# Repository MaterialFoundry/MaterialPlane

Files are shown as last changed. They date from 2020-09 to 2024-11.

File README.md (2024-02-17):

<b>This module requires external hardware that you probably don't have lying around, which means that you have to spend (at least) $40 on getting this module to work. The module is still in development, and probably contains bugs. Make sure that you're willing to risk spending money on something that might not work as intended.<br></b>
<br>
You can currently place a pre-order for pre-build hardware from my webshop: <a href="https://www.materialfoundry.nl/">https://www.materialfoundry.nl/</a><br>

### [Documentation](https://materialfoundry.github.io/MaterialPlane/)

# Material Plane
Material Plane is a <a href="https://foundryvtt.com/">Foundry VTT</a> module that allows physical minis to be tracked by Foundry when using a horizontally mounted TV. This allows you to bring the joy of physical minis into Foundry.<br>
<br>
There are currently 2 ways to track minis:<br>

## Material Plane sensor
The system consists of an IR sensor, and IR enabled mini bases. These bases contain IR LEDs that are tracked by the sensor. The sensor then relays this information to foundry over WiFi, where the information is interpreted as token movement.<br>
You can use any TV, monitor or projector for this.<br>
There is a pre-assembled and advanced version of the hardware for sale on the [Material Foundry webshop](https://www.materialfoundry.nl/), or it is possible to build DIY hardware.

## Touch Screen
There is currently experimental support for touch screen devices (broken in Foundry v11, though). Either capacitive touch screens or normal TVs with an IR touch frame can work.<br>
<br>
Please take a look at [this](https://materialfoundry.github.io/MaterialPlane/hardwareComparison/) page for a comparison between the Material Plane sensor and touch screen.<br>

## Trailer
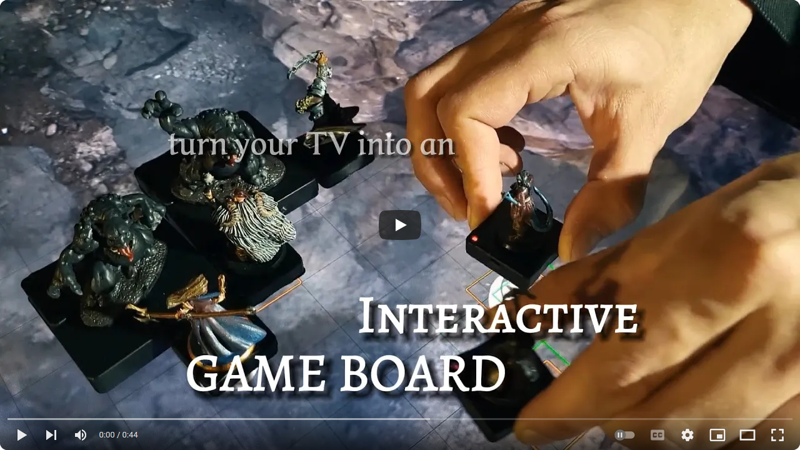
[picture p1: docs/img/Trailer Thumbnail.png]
Youtube Video (https://www.youtube.com/watch?v=VVTjNrCfUwM "Trailer")


# Important Links
* [Documentation](https://materialfoundry.github.io/MaterialPlane/)
* [Issues/Feature requests](https://github.com/MaterialFoundry/MaterialPlane/issues)
* [Main repository](https://github.com/materialfoundry/materialplane)
* [Foundry module](https://github.com/MaterialFoundry/MaterialPlane_Foundry) ([Releases](https://github.com/MaterialFoundry/MaterialPlane_Foundry/releases))
* [Sensor firmware](https://github.com/MaterialFoundry/MaterialPlane_Sensor) ([Releases](https://github.com/MaterialFoundry/MaterialPlane_Sensor/releases))
* [Base firmware](https://github.com/MaterialFoundry/MaterialPlane_Base) ([Releases](https://github.com/MaterialFoundry/MaterialPlane_Base/releases))
* [Pen firmware](https://github.com/MaterialFoundry/MaterialPlane_Pen) ([Releases](https://github.com/MaterialFoundry/MaterialPlane_Pen/releases))
* [Material Companion](https://github.com/MaterialFoundry/MaterialCompanion) ([Releases](https://github.com/MaterialFoundry/MaterialCompanion/releases))
* [Arduino core](https://github.com/MaterialFoundry/MaterialFoundry_Arduino) ([Releases](https://github.com/MaterialFoundry/MaterialFoundry_Arduino/releases))
* [3D models](https://github.com/MaterialFoundry/MaterialPlane_Models)
* [Discord server](https://discord.gg/3hd4G6TkmA)
* [Patreon](https://www.patreon.com/materialfoundry)

## Software Versions & Module Incompatibilities
<b>Foundry VTT:</b> v10 & v11<br>
<b>Module Incompatibilities:</b> When moving tokens, Foundry's click and drag system is bypassed. So modules that depend on that functionality might not work.<br>

## Feedback
If you have any suggestions or bugs to report, feel free to contact me on Discord (Cris#6864), or send me an email: cdeenen@outlook.com.

## Credits
<b>Author:</b> Cristian Deenen (Cris#6864 on Discord)<br>
<br>
Please consider supporting me on <a href="https://www.patreon.com/materialfoundry">Patreon</a>, and feel free to join the Material Foundry <a href="https://discord.gg/3hd4G6TkmA">Discord</a> server.

## Abandonment
Abandoned modules are a (potential) problem for Foundry, because users and/or other modules might rely on abandoned modules, which might break in future Foundry updates.<br>
I consider this module abandoned if all of the below cases apply:
<ul>
  <li>This module/github page has not received any updates in at least 3 months</li>
  <li>I have not posted anything on "the Foundry" and "the League of Extraordinary Foundry VTT Developers" Discord servers in at least 3 months</li>
  <li>I have not responded to emails or PMs on Discord in at least 1 month</li>
  <li>I have not announced a temporary break from development, unless the announced end date of this break has been passed by at least 3 months</li>
</ul>
If the above cases apply (as judged by the "League of Extraordinary Foundry VTT Developers" admins), I give permission to the "League of Extraordinary Foundry VTT Developers" admins to assign one or more developers to take over this module, including requesting the Foundry team to reassign the module to the new developer(s).<br>
I require the "League of Extraordinary Foundry VTT Developers" admins to send me an email 2 weeks before the reassignment takes place, to give me one last chance to prevent the reassignment.<br>
I require to be credited for my work in all future releases.

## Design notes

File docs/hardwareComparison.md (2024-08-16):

# Hardware Comparison
There are a few options when it comes down to the tracking of physical miniatures. This page will give an overview of these options, and a comparison between them.

## Options

### Material Plane Hardware

The first option would be to use a Material Plane sensor. The setup consists of 2 parts:

1. A sensor, which is mounted above the TV, and basically functions like an IR camera
2. Mini bases, which are placed underneath the mini and contain an IR LED which can be tracked by the sensor

There are 2 variants, the DIY variant and the production variant. The DIY variant has to be assembled by the user, while the production variant comes pre-assembled, and is available at the [Material Foundry webshop](https://www.materialfoundry.nl/).<br>
The main differences between the two variants can be found in the comparison below.<br>

The Material Plane sensor can be used on almost any display, for example a normal TV, or a projector.<br>

Because the minis are only detected when they are moved, there is no limit the the amount of minis you can have on the table. There is, however, a limit to the amount of minis that can be moved at the same time: 4 for the DIY sensor and 16 for the production sensor.<br>

Other forms of interaction (besides moving minis) is not possible for the DIY sensor, while the production sensor supports a special pen that can be used like a mouse to open doors, draw shapes, place templates, etc.<br>

Because the sensor is mounted above the TV, contact with the TV while moving minis is not required, unlike other setups. This means that minis can be raised up into the air in order for them to be moved over other minis.

### Infrared Touch Screen
<b>Material Plane support for touch screens is currently experimental. It is not yet clear how well it actually works, so it is currently not advisable to purchase one specifically for this purpose.</b><br>

An IR touch screen uses IR LEDs on 2 sides of the screen, and sensors on the other 2 sides. By placing a finger (or mini) on top of the screen, a shadow is cast on the sensors, because the IR light cannot pass through your finger. This is then converted to a position, which is interpreted as a touch by the computer.<br>

These touch screens can generally detect up to 10 touch points, however, these are not completely independent. Because the touch points cast a shadow, blind spots (where no touch is detected) are possible, and touches on one side of the display can influence the detected position of other touch points.<br>

Because the IR LEDs and sensors are slightly above the TV, it might be necessary to place the minis on a small platform to ensure that they are detected by the sensors.<br>

A non-touch display can quite easily be converted to an IR touch display through an IR touch frame. They can be easily found on, for example, Amazon for around $150 to $300 (depending on size and vendor).<br>

Other forms of interaction (besides moving minis) is possible, but is limited by the algoritm that distinguishes minis from other touches.

### Capacitive Touch Screen
<b>Material Plane support for touch screens is currently experimental. It is not yet clear how well it actually works, so it is currently not advisable to purchase one specifically for this purpose.</b><br>

A capacitive touch screen uses capacitive sensing to detect touches. I will not go into detail on how this works, for more information, take a look on [Wikipedia](https://en.wikipedia.org/wiki/Capacitive_sensing). The most important things are that capacitive touch screens only detect certain objects, such as fingers, while other objects are not detectable. This requires some modification to each mini that has to be detected, to basically create electrical contact between the screen and a hand through the mini. This could be done by, for example, applying copper tape to the bottom of the mini, with a piece of that tape extending up, so that it can be touched when the mini is moved.<br>

Unlike an Infrared touch frame, the touch points of a capacitive touch screen are independent. The number of detectable touch points is generally 10, but this can be higher or lower, depending on the display. Depending on how the minis are detected, this limit might not be important. In the above case (using copper tape), the mini is only detected when the mini is touched, therefore you could add as many minis as you like, as long as you only touch up to 10 at the same time.<br>

Big displays with built-in capacitive touch screens are hard to find and expensive. Capacitive touch can be added to existing non-touch displays (search for 'touch foil' or 'pcap touch foil'), but these are more difficult to find than IR touch frames. These foils generally have to be glued to the display or a separate glass pane, which can be difficult to do properly (due to trapped bubbles)<br>

Other forms of interaction (besides moving minis) is possible, but is limited by the algoritm that distinguishes minis from other touches.<br>

## Comparison
| |DIY|Production|IR Touch|Capacitive Touch|
|-|-|-|-|-|
|Max nr of minis on TV|Unlimited|Unlimited|10<sup>1</sup>|Unlimited<sup>2</sup>|
|Max nr of simultaneously moved minis<sup>3</sup>|4|16|10<sup>1</sup>|10|
|Other interaction methods<sup>4</sup>|No|Yes (through pen)|Yes (potentially limited)|Yes (potentially limited)|
|Required hardware|Sensor + Bases|Sensor + Bases|Screen and Touch Frame<sup>5</sup>|Just the screen<sup>6</sup>|
|Detection limitations|Line of sight required<sup>7</sup>|Line of sight required<sup>7</sup>|Touch points are not independent, contact with TV must be maintained|Contact with TV must be maintained|
|Display limitations|Can work on any display, but with size limitation<sup>8</sup>|Can work on any display, but with size limitation<sup>8</sup>|Requires either built-in touch, or a fitting touch frame|Requires either built-in touch, or a fitting touch foil|
|Mini movement method|Button press on base|Touch sensors on left and right side of the base|Raise a mini and then place it down again before moving the mini|Touching the conductive part of the mini<sup>2</sup>|
|Mini identification<sup>9</sup>|Location based|ID based|Location based|Location based|
|Portability|Can be easily transported somewhere else, to be used on a different display|Can be easily transported somewhere else, to be used on a different display|Requires the display (or touch frame) to be transported|Requires the display to be transported|
|Availablility|Must be built by yourself, some parts can be difficult to source|[Webshop](https://www.materialfoundry.nl/)|Touch frames are easy to find online|TVs with built-in capacitive touch are expensive and difficult to find, touch foil is difficult to find (price unknown)|
|Price (excluding display)|$50 - $100|$200-$400|$150 - $300|Intrated: very expensive, foil: $150-$400 |
|Current state|Functional|Functional|Experimental (broken in Foundry v11)|Experimental (broken in Foundry v11)|

<sup>1</sup> This is a theoretical limit, issues might occur before them due to the shadow effect, as described above<br>
<sup>2</sup> Depends on how the minis are detected, see above<br>
<sup>3</sup> This is a theoretical limit, your computer might not be able to process more than a few minis at the same time<br>
<sup>4</sup> This includes things like opening doors, placing templates, using measurement tools, etc<br>
<sup>5</sup> It might be necessary to place something underneath the mini to raise them, see above<br>
<sup>6</sup> Minis might require modification to add a conductive part, see above<br>
<sup>7</sup> Line of sight is required between the IR LED in the base and the sensor, care must be taken in how to hold a mini, and how to position minis on the base<br>
<sup>8</sup> The MP sensor is basically an IR camera, this means that any kind of display (TV, projector, etc) is compatible, as long as it's not too big. The maximum size depends on the distance between the sensor and the display, more info [here](https://github.com/CDeenen/MaterialPlane/wiki/Requirements#horizontally-mounted-tv).<br>
<sup>9</sup> Identification in this case means the method that is used to identify which mini is moved, and how this is related to the digital tokens. Location based means that it will link the token that's nearest to the mini, while ID based means that it is always known which mini is moved though a unique ID, regardless of the mini's location relative to its digital token.

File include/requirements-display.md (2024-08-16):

You'll need a TV, or some other display (monitor/projector) onto which the virtual tabletop is displayed.

{% if variant != 'touch' %}
For the Material Plane hardware (both DIY and production) you do have to consider the size of your TV, due to the limited detection angle of the sensor, see [Display-Sensor Distance section](requirements.md#display-sensor-distance) below.
Virtually any display will work, however, some older models (especially plasma and LCD displays with CCFL backlight) can emit infrared noise which might interfere with the sensor. To remedy this, you could add infrared-blocking foil to the display. Modern displays should not cause any issues.
{% endif %}

{% if variant == 'touch' %}
If the display has touch capabilities built-in there are no further requirements. Otherwise, make sure that your infrared touch frame or capacitive touch foil is the correct size and mounted correctly.
{% endif %}

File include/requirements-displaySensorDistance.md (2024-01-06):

In order for the sensor to detect minis across the whole display, the sensor needs to be located at a minimum distance above the display. The minimum distance depends on the size of the display, where a bigger display requires a larger distance.

{% if variant == 'production' %}
A [wide-angle lens]({{lensLink}}) can be installed in the production sensor when your display is too big and/or the distance to the ceiling is too small. The lens can either come pre-installed by selecting the option in the sensor product page, or it can be bought separately.
{% endif %}

The table below gives the minimum distance between the display and sensor. Measure the distance between the top of the display and the desired sensor mounting location (ceiling, microphone stand, etc). 

{% if variant == 'production' %}
Look at the row with your display size:

* If the measured distance is smaller than the value in the 'With Lens' column, your setup is incompatible with Material Plane. 
* If the distance is larger than the value in the 'With Lens' column but larger than the 'Without Lens' column, your setup requires the wide-angle lens. 
* If the distance is larger than the value in the 'Without Lens' column, the lens is not required, but can still be used to decrease the distance between sensor and display.
{% else %}
Look at the row with your display size, and if the value in the 'Distance' column is smaller than the measured distance, your setup is incompatible with Material Plane.
{% endif %}

Placing the sensor too far away from the display will result in reduced accuracy and potentially more jittery movement. For optimal results you should place the sensor as close to the minimum distance as possible (with some wiggle room for alignment). If you do not need the wide-angle lens, it's better to not have it installed.

Please note that these are just approximate values, assuming a 16:9 aspect ratio display and perfect sensor positioning while ignoring any manufacturing tolerances. Try to err on the safe side by subtracting a few cm/inches from the measured distance between display and sensor.

{% if variant == 'production' %}
Display Size | Production (No Lens) | Production (Lens) 
-------------|----------------------|-------------------
32" 	     | 109cm/43" 	        | 88cm/35"          
40" 	     | 134cm/53" 	        | 108cm/43"         
43" 	     | 144cm/57" 	        | 116cm/46"         
50" 	     | 166cm/66" 	        | 134cm/53"         
55" 	     | 182cm/72" 	        | 146cm/57"         
60" 	     | 198cm/78" 	        | 159cm/63"         
65" 	     | 214cm/85" 	        | 172cm/68"         
70" 	     | 230cm/91" 	        | 185cm/73"         
75" 	     | 246cm/97" 	        | 198cm/78"         
80" 	     | 278cm/110" 	        | 223cm/88"         
{% else %}
Display Size | Distance
-------------|--------
32" 	     | 120cm/47"
40" 	     | 150cm/59"
43" 	     | 160cm/63"
50" 	     | 187cm/74"
55" 	     | 205cm/81"
60" 	     | 224cm/88"
65" 	     | 243cm/96"
70" 	     | 261cm/103"
75" 	     | 280cm/110"
80" 	     | 289cm/114"
{% endif %}

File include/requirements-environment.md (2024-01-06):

Because of the way the sensor works, any infrared light around the TV can be interpreted as a base. For this reason, ambient infrared radiation and reflection should be avoided.

* Sunlight
* Infrared Emitting Lights
* VR Headsets
* Wii Sensor Bar
* Remote Controls

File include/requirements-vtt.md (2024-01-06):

Material Plane runs on a virtual tabletop. Currently only [Foundry VTT](https://foundryvtt.com/) is supported.

To use Foundry VTT, you need to purchase a license, and you need some way to host the Foundry server. For information on how to setup a Foundry VTT server, please refer to the [Foundry VTT Knowledge Base](https://foundryvtt.com/kb/). Alternatively, you could using a hosting service such as [The Forge](https://forge-vtt.com/), [Molten Hosting](https://moltenhosting.com/) or [Foundry Server](https://www.foundryserver.com/).

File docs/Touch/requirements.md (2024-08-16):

{%set variant = 'touch' %}

# Requirements
The requirements for using Material Plane using touch can be divided into 3 parts:

* [Touch-related hardware](#touch-related-hardware)
* [Compatible Minis](#compatible-minis)
* [Virtual Tabletop](#virtual-tabletop)
* [Horizontally mounted display](#horizontally-mounted-display)

# Touch-Related Hardware
Some kind of hardware is required that can detect touches. While there are more options, the following 3 will be the most commong:

* <b>Integrated capacitive touch:</b> A display with integrated touch layer. These tend to be very expensive, but are a good choice due to their accuracy, easy of use, and number of touch points.
* <b>Infrared Touch Frame:</b> Touch frames work by sending a beam of IR light across the surface of the TV. If this light is interrupted, the location is calculated and registered as a touch point. Infrared touch frames are relatively inexpensive and easy to mount to an existing display.
* <b>Capacitive Touch Foil:</b> This is a foil that is attached to a non-touch display to give it capacitive touch. Can have similar advantages to integrated touch screens, but can be difficult to apply properly (without bubbles).

# Compatible Minis
<b>Infrared Touch Frames:</b><br>
There are 2 challenges related to infrared touch frames:

* The IR beam is located slightly above the surface of the TV (probably a few millimeters)
* Small objects might not be detected This means that the touch frame might have trouble detecting certain minis. If the base of the mini is thin, it's possible that the IR beam is at the height of the legs of that mini, which might be undetectable.<br>
The easiest way to solve this, would be to increase the height of the base, by, for example, glueing some object to the bottom of the base.

<b>Capacitive Screens:</b><br>
In simple terms, a capacitive screen works by sensing a change in capacitance caused by touch. For this to function for minis (or other objects), the mini must be conductive, or at least, there must be a conductive path from your finger to the touch screen. Below are 2 methods to achieve this.

* Copper Tape<br>
Buy copper (or other conductive) tape, cut of a piece (try around 3 or 4 cm), and place it on the bottom of the base in such a way that a part of the tape extends past the base. Fold the extending part up (towards the top of the mini). Optionally, you can fold the extending part of the tape double, so it sticks to itself, and not to the mini (or to your finger). When you want to move the mini, you will have to continuously touch the copper tape.
* Conductive Paint<br>
This may or may not work, but it is possible to buy (transparent) conductive paint. Spray this across the whole mini, including the bottom of the base. You might need multiple coats to achieve a low enough resistance.

## Virtual Tabletop
{% include 'requirements-vtt.md' %}

## Horizontally Mounted Display
{% include 'requirements-display.md' %}

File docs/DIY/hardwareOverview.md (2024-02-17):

For the DIY hardware you will, as the name suggest, do it yourself. This includes sourcing parts, basic soldering, 3D printing (for the Full sensor). You will be responsible for all troubleshooting.<br>

<b>It is your own responsibility to properly build and use the hardware.<br>
Material Foundry cannot be held responsible for any damage, either directly or indirectly caused by Material Foundry or any associated hardware, software or service.<br>
This includes damage caused by incorrect documentation, bugs in the software/firmware or wrong advise.</b>

## Sensor
The sensor is responsible for detecting the location of bases, onto which minis are placed. 
The sensor has a special infrared camera that can track sources of infrared light. 
After calibrating the sensor, the sensor can transmit the exact location of bases to the VTT over (2.4GHz) WiFi or USB, which can then move tokens.

A maximum of 4 minis can be moved at the same time, but you can have as many minis on your display (just don't move more than 4 at the same time).

For the DIY sensor, you have 2 options:

* Basic: The most barebones version, just enough to use Material Plane
* Full: A complete device that adds an enclosure, battery charging and more

See the table below for a comparison, where you should consider everytying to be identical, except for the listed items.

| | Basic Sensor  | Full Sensor |
|---|---|---|
| Required materials | Only microcontroller and infrared tracking sensor | Much big list of [requirements](BuildInstructions/sensorFull.md#requirements)
| Microcontroller | Basically any ESP32 or ESP32-S3 board<br> Check the [compatible boards](BuildInstructions/sensorBasic.md#compatible-boards) section  | Must use eiter a TinyPICO or TinyS3  |
| Battery | No battery or battery charging | With battery and battery charging |
| Indicator LEDs | None | Battery and connection indicator LEDs |
| Enclosure | None | 3D printed
| USB Detection | None | Included

## Base

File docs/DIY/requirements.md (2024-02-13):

{%set variant = 'diy' %}

# Requirements
The requirements for using Material Plane using the DIY hardware can be divided into 4 parts:

* [Material Plane hardware](#material-plane-hardware)
* [Virtual Tabletop](#virtual-tabletop)
* [Horizontally mounted display](#horizontally-mounted-display)
* [Suitable environment](#suitable-environment)

## Material Plane Hardware
The DIY hardware consists of 2 items:

* [Sensor](BuildInstructions/sensorFull.md)
* One [Bases](BuildInstructions/base.md) for each mini you want to track

You will need to build this hardware yourself (click on the links above for instructions), the requirements for building them is included in the instructions.

Regarding the bases: you will have to determine how many you think you will need. You will want to have at least one for each player character, and maybe some extra for other minis that have to be tracked, such as familiars or important NPCs.<br>
You can track monsters, if you want to, but for most people this is not necessary (since you probably don't want to share the monters' vision with the players) and a lot of people choose to just place the minis on the display without tracking them.

Because the sensor is essentially a camera, you will need to take the distance between the sensor and your display, and the size of the display into account. If the display is too large, the sensor might not be able to see the entire display. Please read the [Display-Sensor Distance](requirements.md#display-sensor-distance) section carefully.

## Virtual Tabletop
{% include 'requirements-vtt.md' %}

## Horizontally Mounted Display
{% include 'requirements-display.md' %}

## Suitable Environment
{% include 'requirements-environment.md' %}

## Display-Sensor Distance
{% include 'requirements-displaySensorDistance.md' %}

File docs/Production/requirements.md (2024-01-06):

{%set variant = 'production' %}
{% set lensLink = 'SensorConfiguration/sensorLens.md' %}

# Requirements
The requirements for using Material Plane using the production hardware can be divided into 4 parts:

* [Material Plane hardware](#material-plane-hardware)
* [Virtual Tabletop](#virtual-tabletop)
* [Horizontally mounted display](#horizontally-mounted-display)
* [Suitable environment](#suitable-environment)

## Material Plane Hardware
For the production hardware, the most important requirements are the actual hardware.
The following items are required:

* [Sensor](https://www.materialfoundry.nl/products/sensor)
* [Dock](https://www.materialfoundry.nl/products/dock)
* One [Base](https://www.materialfoundry.nl/products/material-plane-base) for each mini you want to track
* [wide-angle lens](https://www.materialfoundry.nl/products/wide-angle-lens), depending on setup (see [below](#display-sensor-distance))

Various [kits](https://www.materialfoundry.nl/collections/material-plane) are available that contain at least the required components for up to 8 players.

Regarding the bases: you will have to determine how many you think you will need. You will want to have at least one for each player character, and maybe some extra for other minis that have to be tracked, such as familiars or important NPCs.<br>
You can track monsters, if you want to, but for most people this is not necessary (since you probably don't want to share the monters' vision with the players) and a lot of people choose to just place the minis on the display without tracking them.

Because the sensor is essentially a camera, you will need to take the distance between the sensor and your display, and the size of the display into account. If the display is too large, the sensor might not be able to see the entire display. It is possible to install a wide-angle lens into the sensor (or have it pre-installed) to allow you to use bigger displays, or to move the sensor closer to the display. Please read the [Display-Sensor Distance](#display-sensor-distance) section carefully.

Optional hardware:

* [Pen](https://www.materialfoundry.nl/products/material-plane-pen) to add more interaction options, such as opening doors or panning the map
* [Base adapters](https://www.materialfoundry.nl/products/base-adapter) to allow the tracking of bigger minis
* [Base](https://www.materialfoundry.nl/products/base-charging-dock-expansion) or [sensor](https://www.materialfoundry.nl/products/sensor-charging-dock-expansion) charging dock expansions so you can charge more bases at the same time, or charge the sensor on the dock
* [Square](https://www.materialfoundry.nl/products/square-magnet) or [Round](https://www.materialfoundry.nl/products/round-magnet) magnets to easily mount minis to bases

## Virtual Tabletop
{% include 'requirements-vtt.md' %}

## Horizontally Mounted Display
{% include 'requirements-display.md' %}

## Suitable Environment
{% include 'requirements-environment.md' %}

## Display-Sensor Distance
{% include 'requirements-displaySensorDistance.md' %}

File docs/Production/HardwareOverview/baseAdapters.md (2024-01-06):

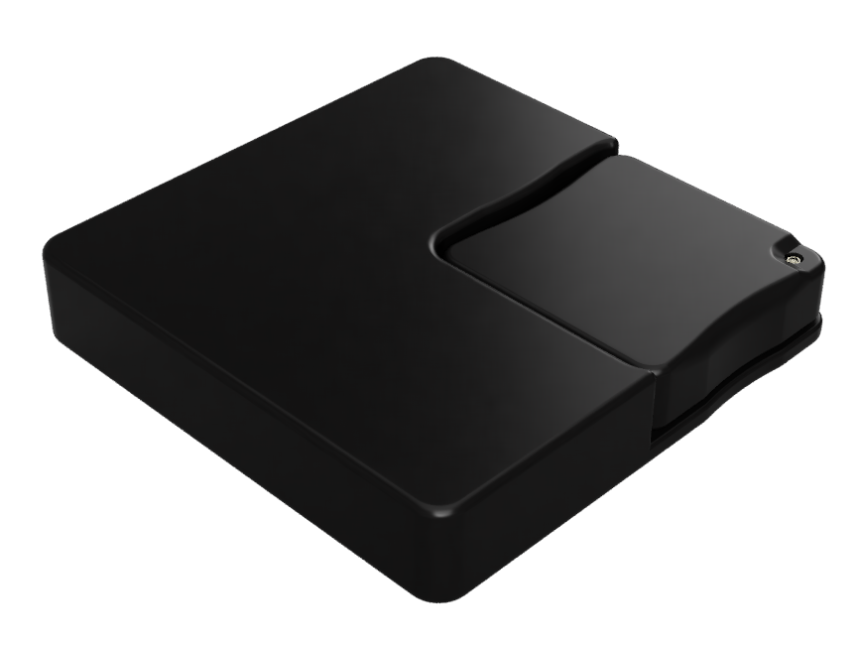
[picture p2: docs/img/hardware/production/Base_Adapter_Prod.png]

Base adapters allow bigger minis to be tracked. Normal bases slot into these adapters, allowing one of the touch sensitive sides of the base to be used to activate the base.<br>
Embedded magnets hold the base in place and allow the mini to be securely attached using square or round magnets or bigger magnetic plates.<br>
The base adapters come in 2x2, 3x3 and 4x4 sizes.

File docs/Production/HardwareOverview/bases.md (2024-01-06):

## Overview

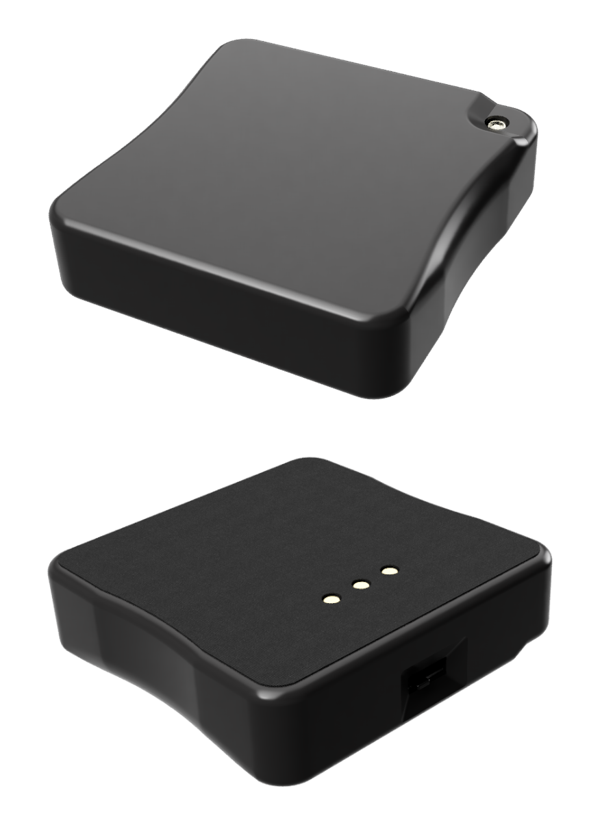
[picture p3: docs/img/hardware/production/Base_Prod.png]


The Material Plane bases are responsible for transmitting the location of a physical mini to the VTT. The base is a small block that is mounted underneath the mini that contains an infrared LED which the sensor can detect.

The base has an infrared and red LED, the infrared LED is used for tracking while the red LED is used as a status indicator, which is hidden inside the enclosure but its light will be visible. The red LED will switch on when the base is active (being moved).<br>
At the top side the base has a power switch, and the left and right side are touch sensitive to activate the base.

The bottom of the base has 3 pins that are used for charging and updating the firmware of the base. Additionally, the bottom of the base is covered by felt to prevent damage to your display.

<b>Specs:</b>

* 120mAh battery
* Charging and programming using the dock
* Infrared tracking and red indicator LEDs
* Power switch
* Felt on the bottom to prevent damage to your display
* 30x30x8mm (WxLxH)
* 8 gram

## Power States
The base has 3 power states:

* <b>Off:</b> The base will not do anything, but can be charged or programmed. The base should be in this state when not in use. 
* <b>Standby:</b> The base is switched on, but not being touched/moved. The base should be in this state when placed on the display during gaming.
* <b>Active:</b> The base is switched on and being touched/moved. Both the red and infrared LED are on and the sensor is able to detect the location of the base.

## Charging
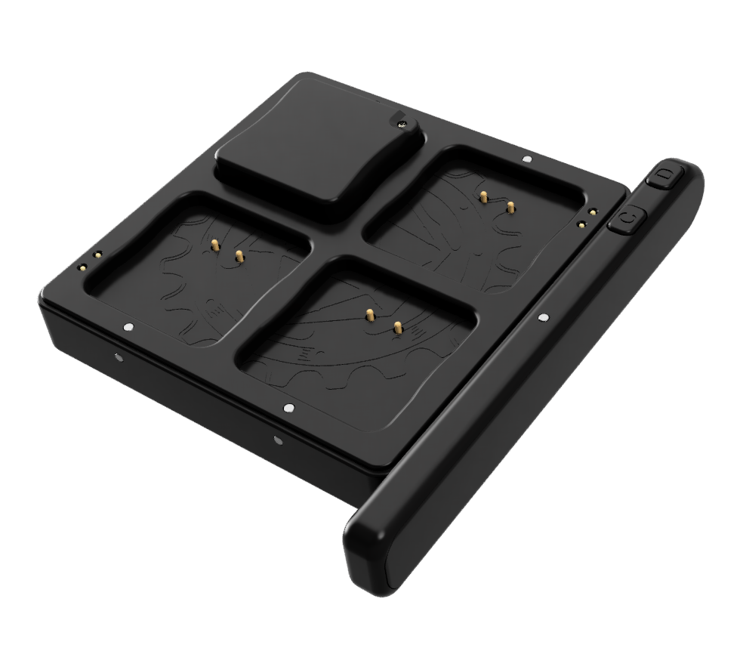
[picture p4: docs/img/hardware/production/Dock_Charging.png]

Bases are charged using the dock or base charging dock expansion. Both have space for charging up to 4 bases simultaneously. Charging is possible due to the spring terminals on the dock or dock expansion, which connect to the terminals at the back of the base.<br>
To charge a base, insert it into one of the four charging slots. The correct orientation is to have the on/off switch of the base towards the top and the USB port of the dock to the left, see the image.<br>
Each charging slot has a status LED which can indicate 3 different states:

* <b>Off:</b> No base connected.
* <b>Red (fading):</b> Base charging.
* <b>Green (static):</b> Base charging completed.

Charging from empty to full takes approximately 90 minutes. Charging can take longer if the power supply cannot provide enough current.

## Battery Life
If the base is off, its power consumption is negligible. When the base has not been used for a few weeks a recharge before a game is recommended. In the standby state, the base will last for more than 24 hours on a full charge. In the active state, the base will last for approximately 2 hours.
During normal gaming, a base is in the standby state the vast majority of the time, only going into the active state whenever the base is being moved. This means that the base might only be in the active state for a few minutes for every hour of gaming. Under normal gaming conditions, you can expect a base to last more than 12 hours on a full charge.

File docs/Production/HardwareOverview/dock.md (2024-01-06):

## Overview
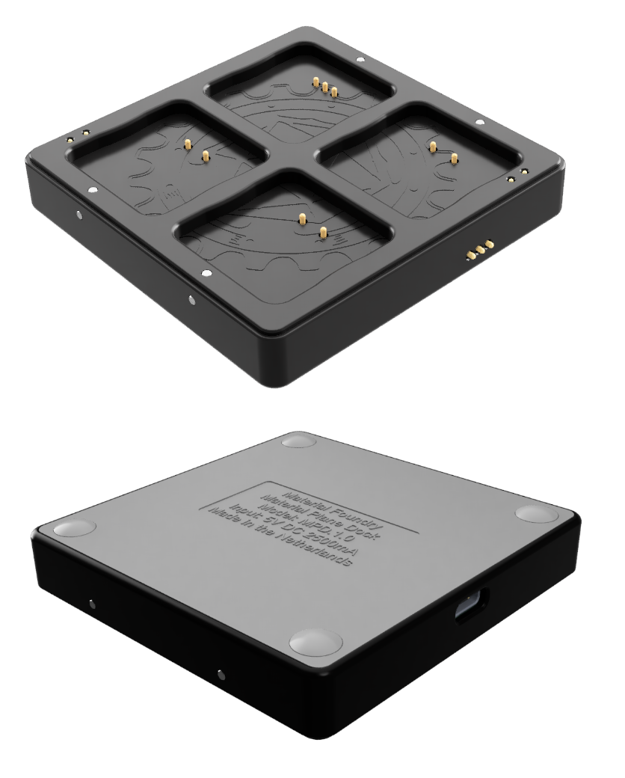
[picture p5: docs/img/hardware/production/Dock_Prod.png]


The dock has 2 main functions: charging and programming the bases and pen. The dock has 4 charging slots for bases and 1 for the pen. The top-left base charging slots (with 3 spring terminals) and the pen charging port can also be used to configure and program the bases and pen.<br>
Powered is delivered through a USB-C connector.<br>
It is possible to stack dock expansions on top of the dock to allow more bases to be charged, or to allow you to charge the sensor using the dock. They are held onto the dock using magnets. You can stack multiple of these expansions on top of each other. Stacking is possible in 2 orientations (rotated by 180 degrees), by aligning the contacts of the dock with the spring terminals on the bottom of the expansion. The magnets in the dock and expansions should prevent incorrect stacking.

<b>Dock Specs:</b>

* Charges up to 4 bases and 1 pen at the same time
* Program and configure bases and pens
* Stack max 4 base charging dock expansions or 2 base and 1 sensor charging dock expansions
* 5VDC at max 2500mA over USB-C
* 81x80x16mm (WxLxH)
* 68 gram

## Base Charging

The dock can charge 4 bases at the same time. The bases are mounted onto the dock using embedded magnets and are charged through the spring terminals. To find the correct base orientation for charging take a look at the underside of a base where you will find 3 contacts. These contacts must mate with the spring terminals on the dock. This is only possible in 1 orientation, see the image on the right.<br>
Each base has its dedicated charge indicator LED which is visible from the top and the side, and can indicate the following 3 states:

* <b>Off:</b> Base not mounted.
* <b>Red (fading):</b> Base charging.
* <b>Green (static):</b> Base charging completed.

## Pen Charging
The dock can charge 1 pen at a time. The pen is mounted onto the side of the dock using embedded magnets and is charged through the spring terminals. Due to the magnet polarity, the pen can only be mounted in 1 orientation (see the image). Do not try to force the pen to connect the dock in the wrong orientation, this can damage the pen, the dock, or both.<br>
Charging is handled inside the pen, for more information on charging, please consult the [pen page](pen.md).

## Base Charging Dock Expansion
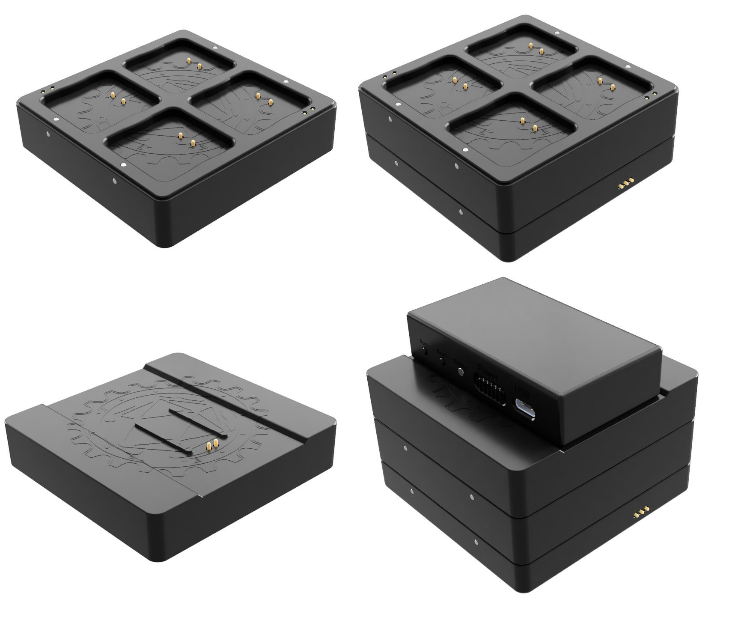
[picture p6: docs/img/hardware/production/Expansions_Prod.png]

Each base charging expansion allows you to charge an additional 4 bases. You should not stack more than 4 base charging expansions on a single dock, allowing you to charge a maximum of 20 bases at the same time. If you also use the sensor charging expansion, you should not stack more than 2 base charging expansions, allowing a maximum of 12 bases.<br>
Charging bases on the base charging expansion is identical to the dock.

<b>Base Charging Dock Expansion Specs:</b>

* Charges up to 4 additonal bases
* 80x80x20mm (WxLxH)
* 82 gram

## Sensor Charging Dock Expanion
The sensor charging expansion allows you to charge the sensor on top of the dock. The sensor charging expansion can be stacked on top of a dock or base charging expansion. You cannot stack expansions on top of the sensor charging expansion.
The sensor has 2 exposed pins on the bottom, these mate with the 2 spring terminals on the sensor charging expansion. By mounting the sensor on the expansion in such a way that the spring terminals align to the exposed pins, the sensor will start charging.

<b>Sensor Charging Dock Expanion:</b>

* Charges the sensor
* 80x80x20mm (WxLxH)
* 65 gram

## Power Supply Requirements
To power the dock and expansions you need a USB charger from a reputable brand. The USB charger should be able to provide approximately 500mA for each dock and each base charging expansion, and 1000mA for the sensor charging expansion. For example:

* A dock without expansions: 500mA
* A dock with a base charging expansion: 1000mA
* A dock with a base charging and sensor charging expansion: 2000mA

## Expansion Stacking Limitations
There is a limit to the amount of expansions you can stack on top of a single dock. This is determined by the charging current of all the parts that are being charged.

It is recommended to stack a maximum of 2 base charging expansions if a sensor charging expansion is also used, for a total of 12 bases. Or a maximum of 4 base charging expansions if no sensor charging expansion is used, for a total of 20 bases.

This is quite conservative, to make sure the fuse inside the dock isn't tripped. However, you can probably get away with stacking more base charging expansions on the dock, because it is unlikely that all bases and the sensor will draw the maximum allowed current, <b>but this is at your own risk</b>.<br>
If your charger cannot provide more than 2500mA, the fuse should never trip, regardless of the amount of expansions you use. This is a safe way to do this, assuming you use a good quality charger. If, in this situation, too many expansions are stacked onto the dock, the power supply voltage may drop which might prevent anything from charging.

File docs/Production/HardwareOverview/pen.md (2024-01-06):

## Overview

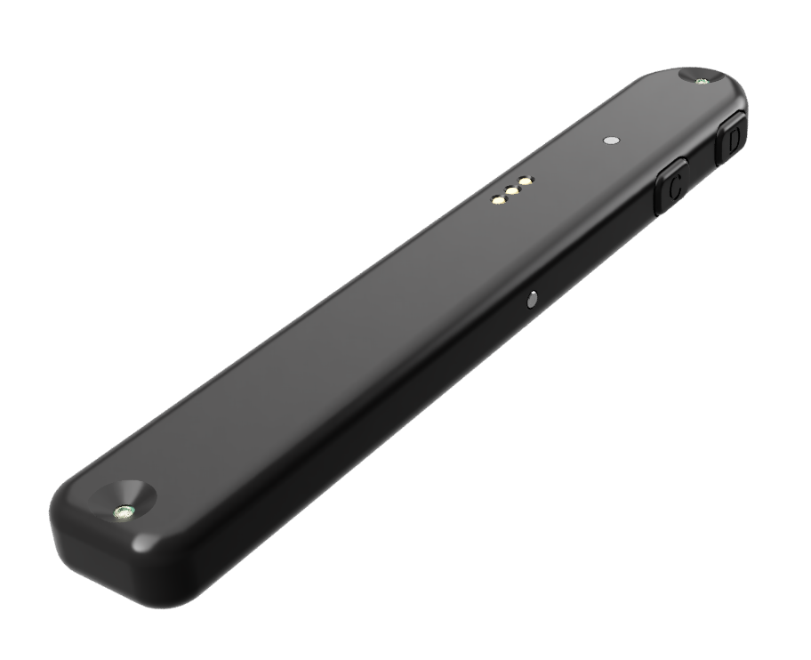
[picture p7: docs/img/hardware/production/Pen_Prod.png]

The pen is an optional accessory that can be used to expand the capabilities of a Material Plane setup. It can be used like a mouse for clicking or selecting things in the VTT, and the sensor can detect the orientation of the pen for rotating objects.<br>
The pen has many functions, such as:

* Moving or rotating tokens
* Targeting tokens
* Panning or zooming the map
* Creating drawings
* Creating templates

The pen has 4 buttons to allow these functions to be performed. Using 2 infrared LEDs the sensor can detect the orientation of the pen for rotation purpose. The pen has a red status LED on the top and a geen/red charging LED on its side. The red LED will switch on when the pen is active, while the green/led charging LED switches on when the pen is charging.

<b>Specs:</b>

* 110mAh battery
* Charging and programming using the dock
* 2 Infrared tracking LED, 1 red indicator LEDs and 1 red/green charge indicator LED
* 4 switches
* 16x105x8mm (WxLxH)
* 13 gram

## Power States
The pen has 2 power states:

* <b>Standby:</b> The pen is not doing anything. It is always in this state unless activated, and it will automatically return to this state after activation.
* <b>Active:</b> One or more of the buttons on the pen is pressed to activate the pen. The red and at least one infrared LED are on and the sensor is able to detect the location of the pen. The pen will stay in this state for a configurable amount of time, after which it will return to the standby state.

## Charging

The pen has to be charged on the dock. The dock has 3 spring terminals sticking out on the right side of the dock (opposite side of the USB port), these mate with 3 contacts on the pen. To charge the pen, orient the pen is such a way that the contacts can touch the spring terminals on the dock, with the side of the pen with C and D buttons pointing to the front, see the image.
The pen is held in place using magnets. You should be prevented from mounting the pen incorrectly due to the magnets. Don’t try to force the pen and dock together if you feel a resistance, incorrectly mounting the pen can damage the dock, pen or both.

When mounted correctly, you can see a status LED on the pen which can indicate 3 different states:

* <b>Off:</b> Pen not mounted correctly.
* <b>Red (fading):</b> Pen charging.
* <b>Green (static):</b> Pen charging completed.

Charging from empty to full takes approximately 90 minutes. Charging can take longer if the power supply cannot provide enough current.

## Battery Life
In the standby state, the pen will last for more than 24 hours on a full charge. In the active state, the pen will last for approximately 2 hours.<br>
During normal gaming, the pen is in the standby state the vast majority of the time, only going into the active state whenever it is used. This means that the pen might only be in the active state for a few minutes for every hour of gaming. Under normal gaming conditions, you can expect the pen to last more than 12 hours on a full charge.

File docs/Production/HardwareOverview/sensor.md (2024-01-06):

## Overview
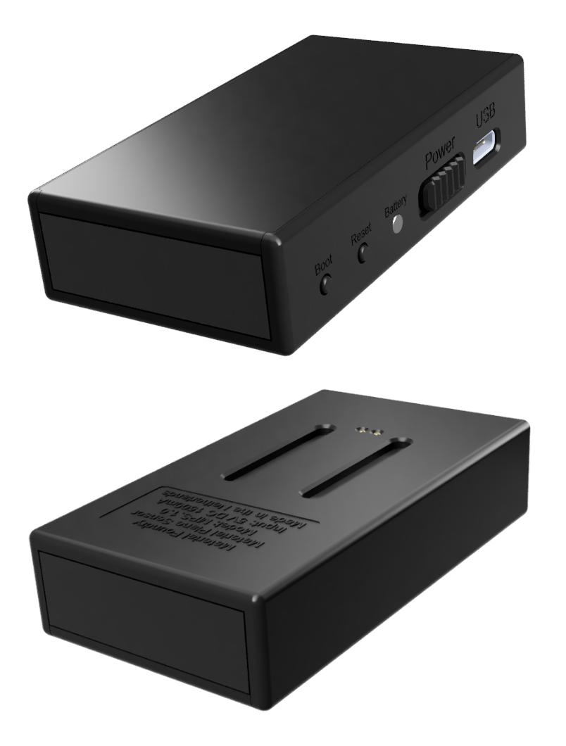
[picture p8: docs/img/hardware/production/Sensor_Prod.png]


The sensor is responsible for detecting the location of bases, onto which minis are placed. The sensor has a special infrared camera that can track sources of infrared light. After calibrating the sensor, the sensor can transmit the exact location of bases to the VTT over (2.4GHz) WiFi or USB, which can then move tokens.

The sensor has some important features on one side, see the image:

* <b>USB-C Connector:</b>  For charging, updating the firmware and alternative connection method.
* <b>Power Switch:</b> Sliding the switch towards the USB connector turns the sensor on.
* <b>Battery LED:</b> Battery and status indicator, see below.
* <b>Reset Switch:</b> Can be pressed to reset the sensor.
* <b>Boot Switch:</b> Can be used, in combination with the reset switch, to select the boot mode of the sensor. Only used for firmware updates, see [here](../Updating/sensorUpdating.md).

The front of the sensor can be identified by the shiny black window. This window only transmits infrared light, allowing the sensor to detect bases. For the best performance, this window should be kept clean.

The bottom of the sensor contains some basic information, such as the product name and model, and the input voltage and (maximum) current draw. There are 2 pins that allow the sensor to be charged on the Sensor Charging Dock Expansion. Embedded into the bottom of the sensor are 4 magnets which allow the sensor to be easily mounted onto the sensor mount or the above mentioned dock expansion. The 2 slots help with aligning the sensor properly on these 2 mounts.

<b>Specs</b>

* USB 2.0 Full Speed over a USB-C connection
* 2.4GHz 802.11b/g/n WiFi
* 1200mAh battery
* 5VDC at max 1500mA over USB-C or sensor charging dock expansion
* Programming through USB or web interface
* Power, reset and boot mode (for programming) switches
* Power and battery indicator LED
* Up to 16 simultaneous trackable bases (you can track as many bases as you want, but only up to 16 can be moved at the same time)
* Mounting on 3/8" microphone stand or 4x35mm countersunk screw into ceiling
* 44x77x18mm (WxLxH)
* 61 gram without mounting hardware, 83 gram with mounting hardware

## Power States
The sensor has 3 power states:

* <b>Off:</b> Power slider is switched to off, and the sensor is not charging. The sensor is completely powered down.
* <b>Active:</b> Power slider is switched to on. The sensor is now functioning normally and can detect bases and pens.
* <b>Charging:</b> Power is applied to the sensor to charge it.

<b>Charging</b><br>
The sensor is charged either using a USB-C cable, or using a sensor charging dock expansion (see below). The sensor can draw up to 1000mA to charge the battery.<br>
The battery LED on the side of the base can indicate 5 different states:

* <b>Off:</b> Sensor is switched off and not charging.
* <b>Red (fading):</b> Sensor is charging.
* <b>Green (static):</b> Sensor charging completed.
* <b>Combination of red and green (static):</b> Indicates a rough battery level, where green means 100% and red means 0%.
* <b>Red (fast blinking):</b> An error has occured.

Charging from empty to full takes approximately 90 minutes. Charging can take longer if the power supply cannot provide enough current.

## Battery Life
Is the sensor is off, its power consumption is negligable. If it is on, the power consumption will depend on the activity. When no base or pen is detected for a while, it will go into low power mode to conserve power. You can expect around 20 hours of battery life for average gaming situations.

## Mounting
A mounting bracket is provided with the sensor, which can be used to mount the sensor to a microphone stand or, for example, the ceiling. More information on how to mount the sensor can be found [here](../SensorPositioning/sensorMounting.md).

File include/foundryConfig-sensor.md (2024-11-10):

## Connection

This tab allows you to configure how the sensor will connect to Foundry.

Depending on your setup, you will either connect the sensor and Foundry directly, or through Material Companion. Please refer to the [Sensor Configuration](../SensorConfiguration/sensorConnecting.md) page for more info on the connection methods and why you would choose one or the other.

* <b>Connection Mode:</b> Sets how Foundry will try to connect to the sensor:
    * <i>Connect Directly to the Sensor:</i> Foundry will attempt to connect directly to the sensor
    * <i>Connect Through Material Companion:</i> Foundry will attempt to connect to Material Companion, which will then attempt to connect to the sensor
    * <i>Don't Connect:</i> Foundry will not attempt to connect to the sensor
* <b>Sensor Module IP Address:</b> The address of the sensor. Find out the address [here](../SensorConfiguration/sensorConnecting.md#sensor-address)
* <b>Material Companion IP Address:</b> The IP address of Material Companion. Find out the IP address [here](https://github.com/MaterialFoundry/MaterialCompanion/wiki/Overview)
* <b>Maximum Connection Attempt:</b> Foundry will attempt to connect to either the sensor or Material Companion for this many times. After that it will stop trying, until it is refreshed

## Sensor
This tab is used to configure the [sensor settings](../SensorConfiguration/sensorSettings.md).

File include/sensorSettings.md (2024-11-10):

This page discusses all settings related to how the sensor detects bases and handles the data related to this.These settings can be accessed through the Foundry [Module Configuration screen](../Foundry/foundryConfig.md) or the [webserver](webserver.md).

The tab is divided into multiple sections which can be expanded or collapsed.

## Coordinates
{% if variant == 'production' %}

{% else %}

{% endif %}

This section displays data of any detected infrared points (such as a base).<br>
A point is a collection of one or more 'pixels' where infrared light was detected. Pixels close to each other will be combined to form a single point.

The top part of this section displays what the sensor can see. Any detected points will be displayed here with each point numbered and given a color.

The middle part gives the data of the first 4 points:

* <b>X/Y:</b> The X and Y coordinates of the point.
{% if variant == 'production' %}
* <b>Average Brightness:</b> The average brightness of all pixels within the point.
* <b>Maximum Brightness:</b> The brightness of the brightest pixel within the point.
{% else %}
* <b>Brightness:</b> The brightness of the point.
{% endif %}
* <b>Area:</b> The size of the point.

{% if variant == 'production' %}
The bottom part gives data transmitted by a detected base or pen (production sensor only):

* <b>ID:</b> The id of the base or pen.
* <b>Command:</b> The transmitted command (for example the buttons pressed on the pen).
* <b>Battery:</b> Approximate battery percentage.
{% endif %}

## Exposure


The exposure section can be used to configure things related to the detection of bases.

There are 2 brightness related settings ('Sensitivity' and 'Minimum Brightness') and an 'Auto Exposure' button.<br>
You should try the auto exposure first:

1. Grab a base and activate it, make sure it stays activated during the auto exposure process. Make sure only one base is visible to the sensor. 
2. Hold the base near the edge of the display
3. Press the 'Auto Exposure' button
4. The sensor will increase the sensitivity until it detects the base and its detected brightness is close to 255

{% if variant == 'production' %}
<b>Tip</b>: You can keep the base activated without touching it: Touch the side of the base very short, wait for the red LED to switch off, touch the side of the base again. Repeat this 5 times and the red LED will start blinking. The base is now in 'always on' mode. You can switch it back by either switching the base off and on, or by doing the same procedure again.
{% endif %}

If the auto exposure did not work:

1. Set 'Minimum Brightness' to around 100
2. Slide 'Sensitivity' all the way down and slowly increase it until the base or pen is detected
3. Keep increasing it until the maximum brightness is between 220 and 255
4. If the base or pen is not detected, try increasing the minimum brightness
5. If the sensor detects more points, increase the minimum brightness
6. In tricky environments (for example with a lot of stray infrared light) you might have to find a balance between the 'Sensitivity' and 'Minimum Brightness' slider
7. Move the base or pen across your display and make sure that the maximum brightness stays well above 'Minimum Brightness'

<b>Update Rate:</b><br>
The update rate controls how often the sensor sends out position data. Higher update rates will improve responsiveness, but might cause problems for slower systems, because line of sight and lighting calculations will have to be made more often. This can especially become evident when multiple bases are moved at the same time.<br>
Set it as high as you system will allow.

<b>Averaging:</b><br>
Averaging will smooth the position data of the bases. The average count equals how many readings are taken and averaged, where a higher value results in a very smooth but less responsive movement, while lower values result in more jittery but more responsive movement.<br>
Try different values to find one that fits best for you.

<div class="warning" style='background-color:#ab4a00; border-radius: 4px; padding:0.7em; color:black; text-align: center;'><span>
After finding a setting that results in a base being detected, you will want to make sure that bases can be detected across the entire display. In some areas of the display (usually near the edges and corners) it will be more difficult for the sensor to detect bases because of the angle between the bases and the sensor. You might have to increase 'Sensitivity' or decrease 'Minimum Brightness'.<br>
<br>
You may also find that you have to slightly reposition the sensor for it to detect the entire display. You might have to adjust the exposure settings afterwards.
</span></div>

## Transform

The 'Transform' section allows you to modify the position data.<br>

<b>Mirroring & Rotation</b><br>
When you move a base horizontally, but the point in the configuration screen moves the other direction, enable 'Mirror X'.<br>
When you move a base vertically, but the point moves the other direction, enable 'Mirror Y'.<br>
When you move a base horizontally, but the point moves vertically, enable 'Rotation'.<br>

<b>Offset & Scaling</b><br>
Offset and scaling can be used to fine tune the position data after calibration.<br>
Using the 'Offset X' and 'Offset Y' sliders you can add a horizontal of vertical offset to the position data.<br>
Using the 'Scale X' and 'Scale Y' sliders you can scale the position data, which in essence stretches the data out. 

## Calibration
The 'Calibration' section of the 'Sensor' tab allows you to enable or disable the calibration, and to perform a calibration procedure.

If the 'Calibration Enabled' or 'Calibration Offset Enabled' boxes are checked, then these calibration procedures are being applied. For easy sensor repositioning, it is advisable that you uncheck these boxes.<br>
<b>Please note that ticking these boxes does not perform an actual calibration procedure.</b>

See [this](../calibration.md) page for information on how to perform the calibration procedure.

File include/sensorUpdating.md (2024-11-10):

The sensor can be updated in 4 ways:

* Using [Material Companion over WiFi](#material-companion-wifi)
* Using [Material Companion with a USB cable](#material-companion-usb)
* Using the [sensor webserver](#webserver)
* Using the [Arduino IDE](#arduino-ide) (USB or WiFi)

{% if variant == 'diy' %}<b>The first time uploading the firmware to the sensor, you must upload using a USB cable (either using Material Companion or the Arduino IDE).</b>{% endif %}

The sensor has 2 different things that require separate updates:

* <b>Firmware:</b> This is the code that is responsible for almost everything the sensor does, except for the webserver
* <b>Webserver:</b> This is the code that is responsible for the webserver

These may or may not receive updates at the same time. Depending on the update method you will either have to update these separately or they can be updated at the same time.

### Finding the Current Version
You can find the versions of the firmware and webserver that are installed on your sensor in one of the following ways:

* <b>Using Material Companion:</b> The versions can be reported in the [Sensor](https://materialfoundry.github.io/MaterialCompanion/materialPlane/#sensor) tab.
* <b>Using the Sensor's Webserver:</b> The versions will be displayed on the [Status](../SensorConfiguration/webserver.md#status-tab) tab.
* <b>Using the Module's Downloads Tab:</b> The versions will be displayed in 'Current' column on the [Downloads](../Foundry/foundryConfig.md#downloads) tab of the Material Plane configuration screen.

### Finding the Latest Version
You can find the latest versions of the firmware and webserver in one of the following ways:

* <b>Using Material Companion:</b> The latest versions are displayed in the 'Update' section in the [Sensor](https://materialfoundry.github.io/MaterialCompanion/materialPlane/#sensor) tab.
* <b>Using the Module's Downloads Tab:</b> The latest versions will be displayed in 'Latest' column on the [Downloads](../Foundry/foundryConfig.md#downloads) tab of the Material Plane configuration screen.
* <b>Using GitHub's Releases Page:</b> The [Releases Page](https://github.com/MaterialFoundry/MaterialPlane_Sensor/releases) on GitHub will list all the latest releases.

## Material Companion (WiFi)

<b>This method requires the firmware of the sensor to be v3.0.4 or later.</b><br>
Material Companion has the option to update the sensor over your WiFi connection. For this to work, you will need to [connect the sensor to your WiFi network](../SensorConfiguration/sensorConnecting.md).<br>
You will need to update the firmware and webserver separately.



1. Open Material Companion and navigate to the 'Sensor' sub-tab within the 'Material Plane' tab.
2. At the bottom 'Update' section, select either 'WiFi - Firmware' or 'WiFi - Webserver' at 'Update Method'
3. At 'Sensor Address' fill in the address of the sensor. By default this is 'materialsensor.local', but this is configurable in the [sensor configuration](../SensorConfiguration/webserver.md#network-tab). You could also fill in the sensor IP address, for example '192.168.1.20'
4. Select the correct hardware variant of your sensor at 'Variant'
5. At 'Firmware Version' and 'Webserver Version', select the version you want to update to the sensor
6. Optionally, you could tick 'Show Pre-Releases' which will allow you to update a pre-release version (not recommended for normal use)
7. Press the 'Update' button
8. A popup will appear that gives the update progress, you can press 'Details' to get more details about the progress.

    

9. If the update went succesfull the sensor will restart

## Material Companion (USB)

Material Companion has the option to update the sensor over USB.<br>
You can update the firmware, the webserver, or both.



1. Open Material Companion and navigate to the 'Sensor' sub-tab within the 'Material Plane' tab.
2. At the top, select the correct 'Sensor USB Port'.
    * The production sensor will show up as 'COM## (Sensor)' or 'COM## (Sensor - Update) If it doesn't show up, try refreshing the USB ports.<br>If it shows up as 'COM## (Sensor)' press and hold the 'boot' button, then press the 'reset' button and release the 'boot' button. After refreshing the USB ports it should show up as 'COM## (Sensor - Update)'.
    * The DIY sensor will show up as 'COM##'. There may be multiple 'COM##' ports, see [here](#finding-the-correct-usb-port) if you are unsure which one is the correct one.
3. At the bottom 'Update' section, select 'USB' at 'Update Method'.
4. Select the correct hardware variant of your sensor at 'Variant'.
5. At 'Firmware Version' and 'Webserver Version', select the version you want to update to the sensor. You can set one to 'none' to prevent one from updating.
6. Optionally, you could tick 'Show Pre-Releases' which will allow you to update a pre-release version (not recommended for normal use).
7. Press the 'Update' button.
8. A popup will appear that gives the update progress, you can press 'Details' to get more details about the progress.

    

9. If the update went succesfull you can restart the sensor.

## Webserver
The firmware or webserver can be updated from the sensor webserver. You will have to update them separate from each other.

1. Download the latest webserver (Webserver.bin) or firmware (Sensor_[variant]_Firmware.bin) from [here](https://github.com/MaterialFoundry/MaterialPlane_Sensor/releases).
2. Navigate to the [sensor webserver](../SensorConfiguration/webserver.md).
3. Press the 'Update' button at the bottom of the 'Status'tab, this will navigate you to the update page.
4. Select either 'Firmware' or 'Webserver', depending on which you want to update.
5. Browse for the firmware or webserver file.
6. The sensor will now be updated and will restart when its done.



## Arduino IDE
The Arduino IDE gives you the option to update the firmware and webserver (separate from each other), and it even gives you the option to make changes to the code.<br>
Steps 1 - 7 will only need to be done once.<br>
You can upload using the Arduino IDE either over the USB cable or over WiFi (requires the firmware of the sensor to be v3.0.4 or later)

1. Download and install the legacy Arduino IDE from [here](https://www.arduino.cc/en/software). Do not download Arduino IDE 2.x.x, you want 1.x.x
2. Download and install the 'esp32fs plugin' from [here](https://github.com/lorol/arduino-esp32fs-plugin)
3. Open the Arduino IDE and navigate to 'File' => 'Preferences'
4. Near the bottom there should be a field for 'Addition Boards Manager URLs', click the button to the right of that field

5. Fill in the following on separate lines<br>
    "https://raw.githubusercontent.com/espressif/arduino-esp32/gh-pages/package_esp32_index.json"<br>
    "https://github.com/MaterialFoundry/MaterialFoundry_Arduino/releases/latest/download/package_materialfoundry_index.json"
    
    

6. Restart the IDE, then navigate to 'Tools' => 'Board: xxx' => Boards Manager, which should open a new window
7. Wait for the window to fully load, then search for and install 'esp32' (not 'Arduino ESP32 Boards') and 'Material Foundry'.

8. Download and extract the 'Source code' from the [latest sensor release](https://github.com/MaterialFoundry/MaterialPlane_Sensor/releases)
9. Open 'Sensor.ino' in the Arduino IDE
10. Navigate to 'Tools' => 'Board: xxx' and select your harware version/board
    * In most cases you will want to select 'Material Foundry' => 'Material Plane Sensor (xxx)', where you replace 'xxx' with your hardware variant
    * If you use a board that does not fit within the default sensor variants, select your board from the 'ESP32 Arduino' list

    

11. Navigate to 'Tools' and select the correct 'Port'.
    * To update over WiFi, select 'materialsensor at x.x.x.x' under 'Network Ports'
    * The production sensor will show up as 'COM## (Material Plane Sensor (Production))' or 'COM## (ESP32S3 Dev Module).<br>If it shows up as 'COM## (Material Plane Sensor (Production))' press and hold the 'boot' button, then press the 'reset' button and release the 'boot' button. After refreshing the USB ports it should show up as 'COM## (ESP32S3 Dev Module)'.
    * The DIY sensor can show up with various names. There may be multiple 'COM##' ports, see [here](#finding-the-correct-usb-port) if you are unsure which one is the correct one

    

12. You can now update either the firmware or the webserver:
    * <b>Firmware:</b> Press the 'Upload' button (arrow pointing to the right in the top-left part of the screen). Then wait for the IDE to compile and then upload the firmware
    
    
    
    * <b>Webserver:</b> Navigate to 'Tools' and select 'ESP32 Sketch Data Upload', select 'SPIFFS' and press 'OK'. Then wait for the IDE to upload the webserver

    

{% include 'findingComPort.md' %}

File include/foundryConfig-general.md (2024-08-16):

You can access the module configuration by opening the 'Game Settings' sidebar tab (on the right of the screen, cog icon), and clicking the 'Material Plane Configuration' button.



The configuration consists of multiple tabs:

## General
{% if variant != 'touch' %}

{% else %}

{% endif %}
This tab is used for general settings for the module.

* <b>Active User:</b> Sets the active user for the module. This user will be the one displayed on the display.
* <b>Device:</b> Sets the kind of device that is used for token tracking, either the 'Material Plane Sensor' or a 'Touch Screen'
{% if variant != 'touch' %}
* <b>Low Battery Notifications:</b> Will pop up notifications if the battery of the sensor, base or pen is low
{% endif %}
* <b>Hide Display Elements:</b> Will hide all display elements (sidebar, buttons, scenes, etc). This can be toggles using the 'Ctrl' key
* <b>Block Interactions:</b> Will block canvas interactions if the Material Plane Configuration window is open. This will, for example, prevent tokens from being moved while adjusting sensor settings

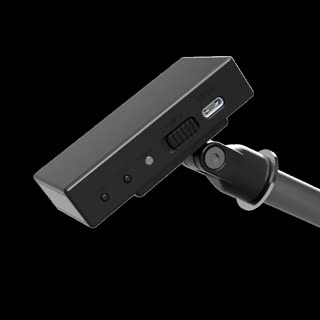
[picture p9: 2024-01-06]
docs/img/hardware/production/.thumb/Sensor_Mount_Microphone.png.jpg

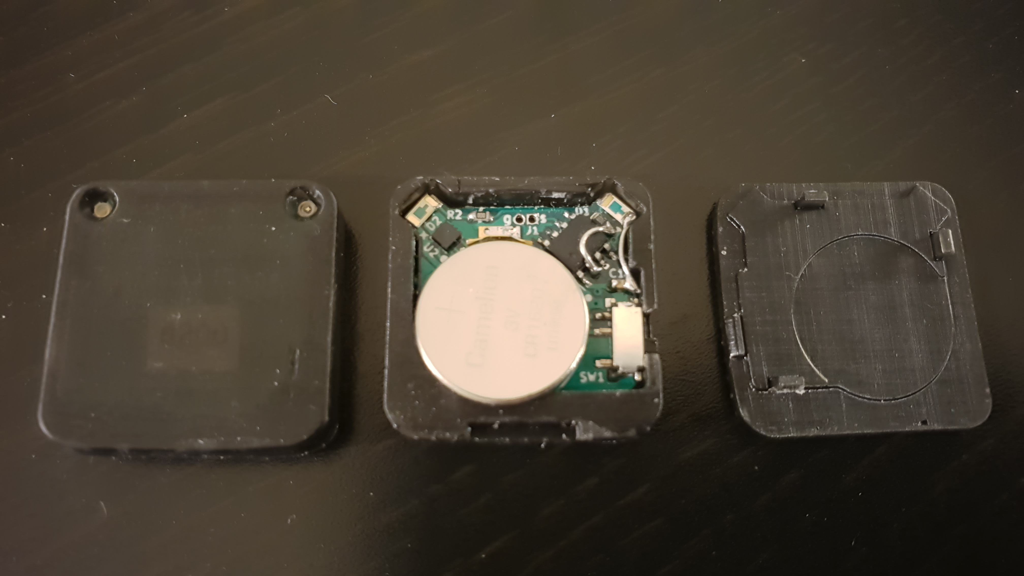
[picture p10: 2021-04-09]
Img/Beta Hardware/MP_Base.jpg

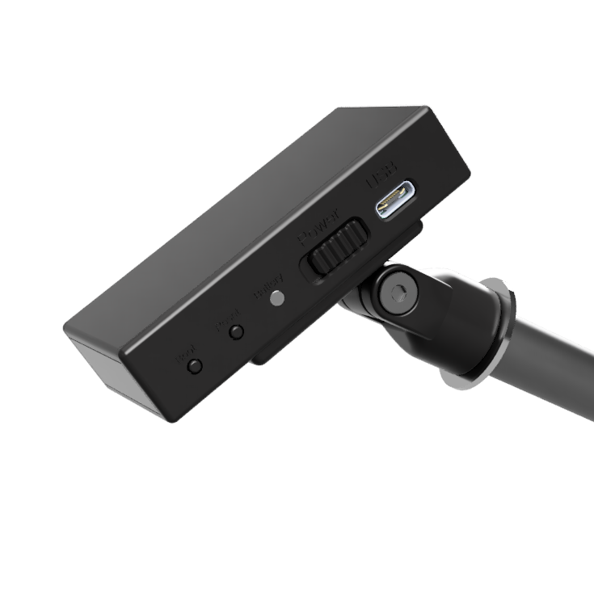
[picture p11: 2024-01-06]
docs/img/hardware/production/Sensor_Mount_Microphone.png

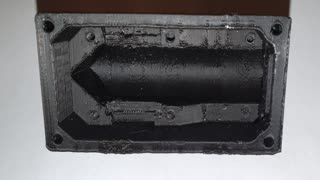
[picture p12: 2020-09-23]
Img/DIY Hardware/.thumb/EmptyEnclosure.jpg.jpg

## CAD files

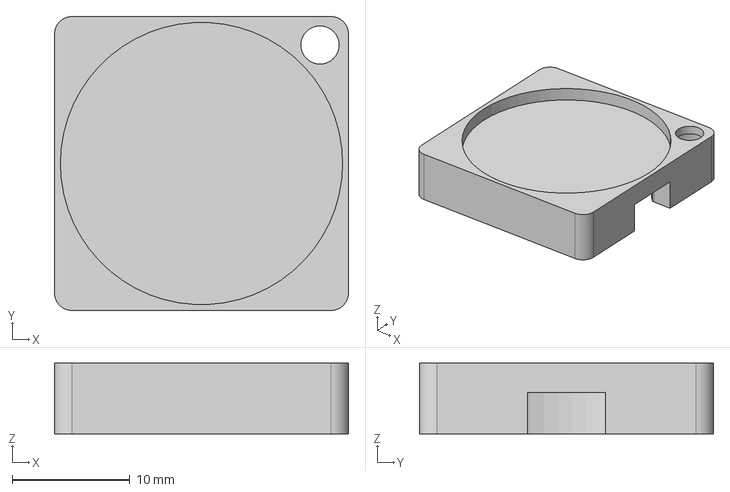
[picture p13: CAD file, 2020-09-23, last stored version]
3D Models/IR Bases/25mm/IR_MiniHolder_25mm_3mmLED_Resin.step
25.0 x 25.0 x 6.00 mm

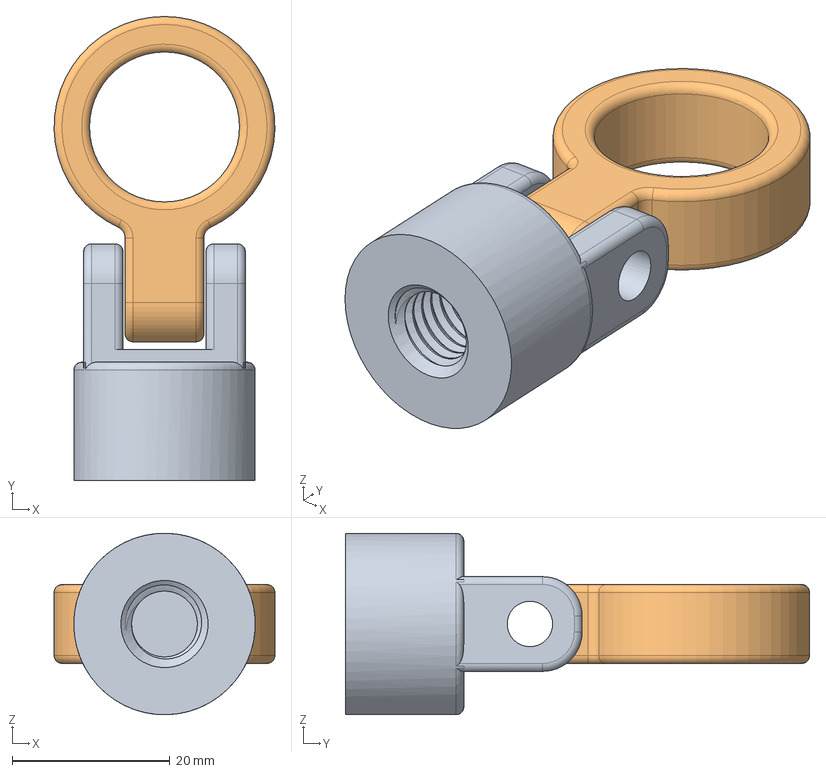
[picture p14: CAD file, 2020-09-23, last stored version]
3D Models/Sensor Mount/SensorMount.step
28.0 x 58.8 x 23.0 mm
Micstand Mount
Sensor Mount

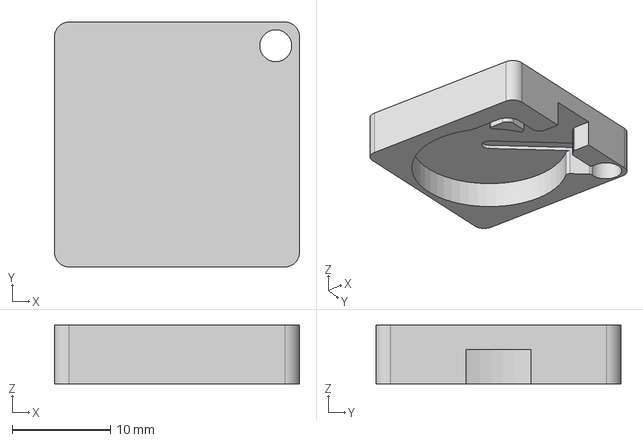
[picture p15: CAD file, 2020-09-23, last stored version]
3D Models/IR Bases/25mm/IR_MiniHolder_25mm_3mmLED_Resin_Flat.step
25.0 x 25.0 x 6.00 mm

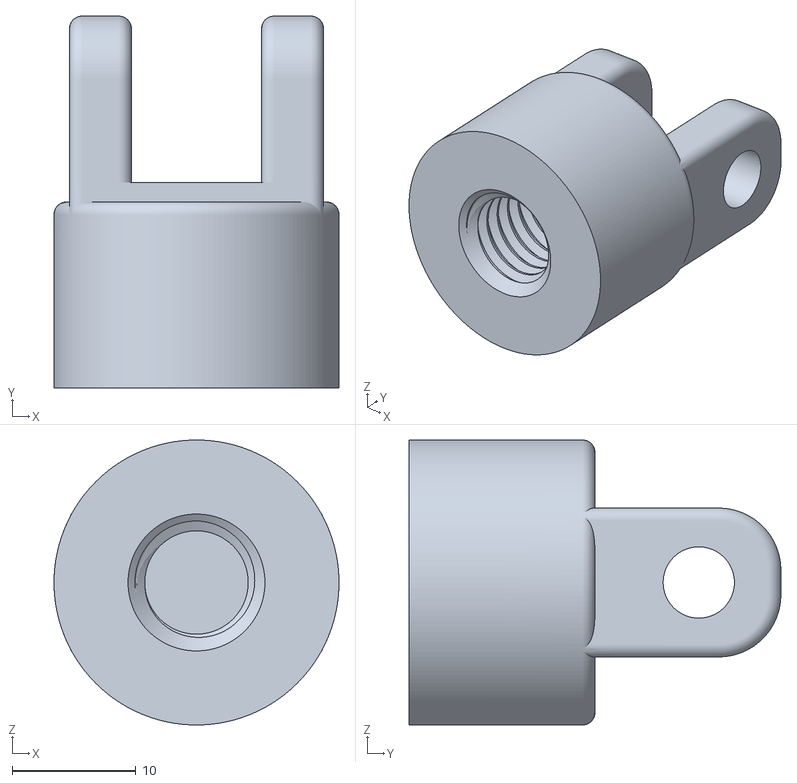
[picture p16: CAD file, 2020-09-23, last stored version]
3D Models/Sensor Mount/Micstand Mount.stl
23.0 x 30.0 x 23.0

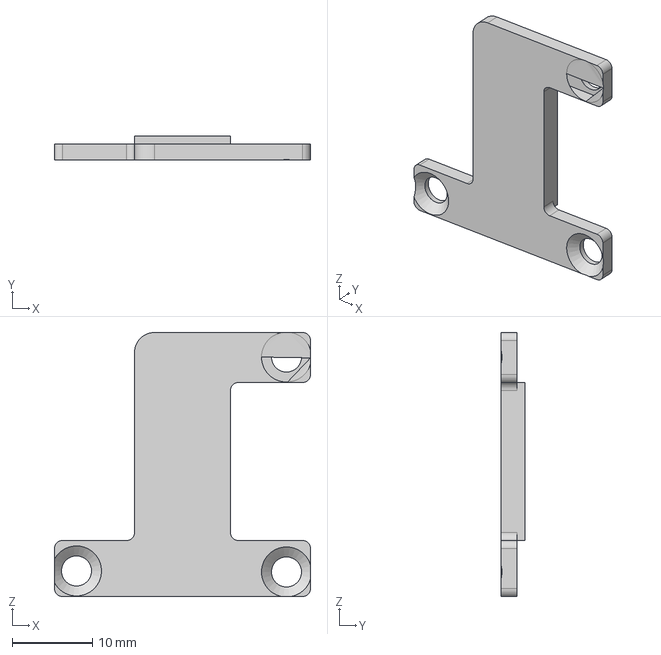
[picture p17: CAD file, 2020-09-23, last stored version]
3D Models/Sensor Enclosure/ControllerBracket.step
32.0 x 3.00 x 33.0 mm

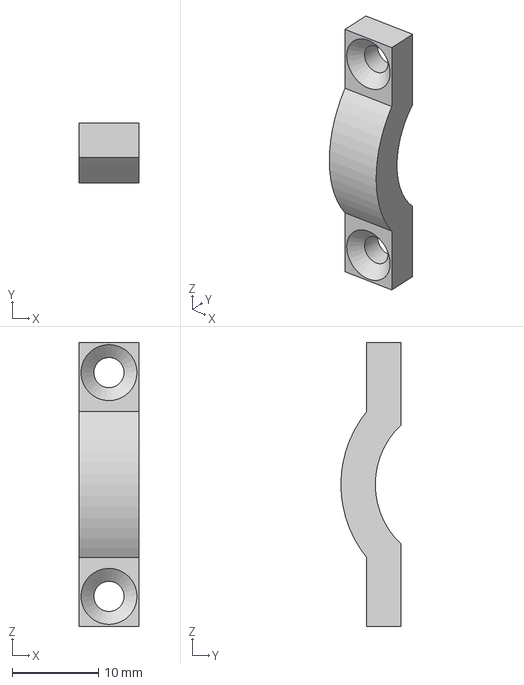
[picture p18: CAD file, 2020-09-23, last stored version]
3D Models/Sensor Enclosure/SensorBracket.step
7.00 x 7.00 x 33.0 mm

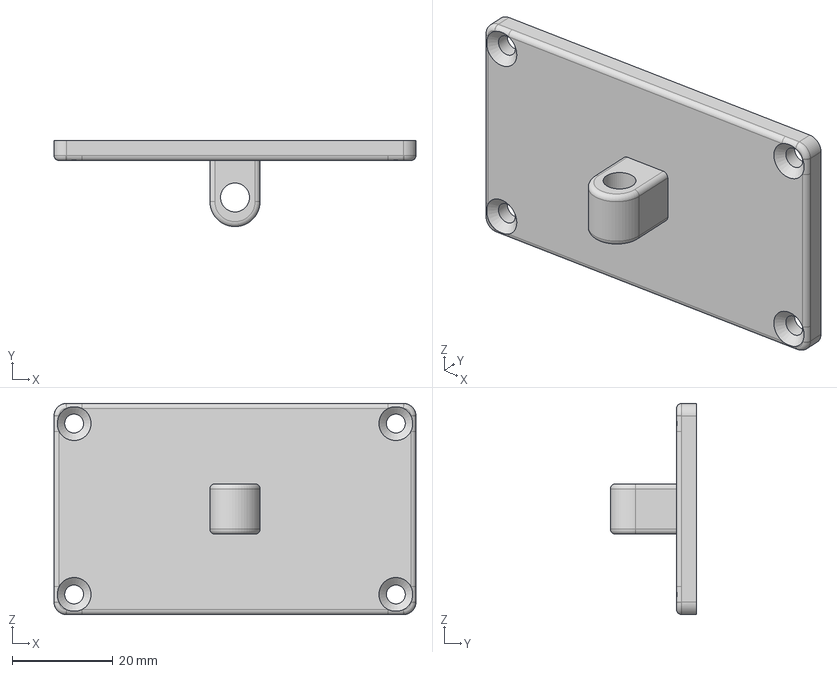
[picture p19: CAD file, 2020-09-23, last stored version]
3D Models/Sensor Enclosure/Lid.step
72.0 x 17.2 x 42.0 mm

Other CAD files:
3D Models/Sensor Enclosure/Micstand Mount.step
3D Models/IR Bases/25mm/IR_MiniHolder_25mm_3mmLED_Resin.f3z
3D Models/IR Bases/25mm/IR_MiniHolder_25mm_3mmLED_Resin.stl
3D Models/IR Bases/25mm/IR_MiniHolder_25mm_3mmLED_Resin_Flat.stl
3D Models/Sensor Enclosure/Complete.f3z
3D Models/Sensor Enclosure/ControllerBracket.stl
3D Models/Sensor Enclosure/Lid.stl
3D Models/Sensor Enclosure/MainBody.stl
3D Models/Sensor Enclosure/SensorBracket.stl
3D Models/Sensor Mount/Sensor Mount.stl

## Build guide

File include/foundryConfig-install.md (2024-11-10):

## Installing the Module
To use Material Plane, you must install the module. There are several ways to do this:

<div class="warning" style='background-color:#ab4a00; border-radius: 4px; padding:0.7em; color:black; text-align: center;'><span>
Please note that you will only need to install the module using <b>one</b> of the following methods (preferably the built-in module browser).
</span></div>

<b>Option 1: Built-In Module Browser</b><br>
The easiest way to install modules is using the built-in module browser.

1. Start Foundry VTT and make sure you're in the 'Setup' screen
2. Navigate to the 'Add-on Modules' tab
3. Press the 'Install Module' button

    

4. Search for 'Material Plane' in the search bar at the top
5. Press the 'Install' button

    

<b>Option 2: Manifest URL</b><br>
You can use the module's manifest URL to install the module. The main reason for this is to install a specific version of the module.

You can find the manifest URL for all available versions [here](https://foundryvtt.com/packages/MaterialPlane).<br>
Choose the version you want, and right-click 'Manifest URL' to copy the URL.

Alternatively, you could use this manifest URL which always points to the latest release:<br>
`https://github.com/MaterialFoundry/MaterialPlane_Foundry/releases/latest/download/module.json`

1. Start Foundry VTT and make sure you're in the 'Setup' screen
2. Navigate to the 'Add-on Modules' tab
3. Press the 'Install Module' button

    

4. At the bottom you can find the 'Manifest URL' field, copy the manifest URL into this field and press 'Install'

    

<b>Option 3: Manual</b><br>
The last option is a manual installation

1. Download the 'module.zip' file from [GitHub](https://github.com/MaterialFoundry/MaterialPlane_Foundry/releases)
2. Extract this file into the 'User Data Path' of your Foundry installation
3. (Re)start Foundry VTT

## Enabling the Module
After installing the module, it must be enabled for each world in which you want to use the module:

1. Start Foundry VTT and the world you want to use it in
2. Open the 'Game Settings' sidebar tab (on the right of the screen, cogs icon)
3. Select 'Manage Modules'

    

4. Search for 'Material Plane' and tick the box to the left of it

    

5. Press 'Save Module Settings'

## Updating the Module
Modules in Foundry do not automatically update. You will have to check regularly if an update is available.<br>
Within Foundry you can either update all modules, or a single module:

1. Start Foundry VTT and make sure you're in the 'Setup' screen
2. Navigate to the 'Add-on Modules' tab
3. Either:
    * Click 'Update All' to update all modules

    

    * Click the update button for the module you want to update

    

## Uninstalling the Module
To uninstall the module:

1. Start Foundry VTT and make sure you're in the 'Setup' screen
2. Navigate to the 'Add-on Modules' tab
3. Right-click the 'Material Plane' icon and click 'Uninstall'



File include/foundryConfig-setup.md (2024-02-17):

## Foundry & System Settings
For Material Plane to work, there are no special requirements with regards to the Foundry core or system settings, and the module is system agnostic.

However, you might want to disable 'Pan to Token Speaker' in the Foundry core settings.

## User Configuration
There will need to be at least 1 gamemaster user for Foundry to work, and for Material Plane to work there needs to be at least 1 player user.<br>
As the gamemaster user you can add users in the 'Game Settings' tab on the right side of the screen by pressing the 'User Management' button. Here you can create an additional user. For the display user this can be either a 'Player' or 'Trusted Player'.

## Actor Permissions
All player characters should be given 'Owner' permission for the display user.<br>
This can be configured in the 'Actors' tab on the right side of the screen. By right-clicking an actor you can select 'Configure Ownership' which opens up a popup in which you can configure which users have what ownership over that actor.

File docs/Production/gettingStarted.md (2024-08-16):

# Getting Started
The Material Plane production hardware is one of the hardware options for Material Plane to track minis on a display.<br>
It comes pre-assembled and can be bought from the [Material Foundry webshop](https://www.materialfoundry.nl/).

The table of contents on the left is ordered in a way that you should start from the top and move your way down, but below you will find a short description of the steps you will need to take to get started:

1. [Make sure you know what the requirements are for using Material Plane](requirements.md)
2. [Figure out what hardware you need](HardwareOverview/sensor.md)
3. [Order the hardware](https://www.materialfoundry.nl/)
4. [Update the sensor firmware](Updating/sensorUpdating.md)
5. [Figure out the optimal sensor mounting method and position](SensorPositioning/sensorMounting.md)
6. [Connect the sensor to your WiFi network](SensorConfiguration/sensorConnecting.md)
7. [Configure the sensor](SensorConfiguration/sensorSettings.md)
8. [Install and configure the VTT module](Foundry/foundryInstall.md)
9. [Calibrate the sensor](calibration.md)
10. [Learn how to properly use the module](Usage/bases.md)

Please check the [troubleshooting](troubleshooting.md) page if you run into any issues.

If you encounter any bugs or wish to request new features, please contact me on Discord (@materialfoundry/@Cris) or post an issue on [GitHub](https://github.com/MaterialFoundry/MaterialPlane/issues).<br>
Consider joining the [Material Foundry Discord Server](https://discord.com/invite/3hd4G6TkmA).

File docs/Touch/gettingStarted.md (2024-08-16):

# Getting Started

<div class="warning" style='background-color:#ab4a00; border-radius: 4px; padding:0.7em; color:black; text-align: center;'>
<span>
<p style='margin-left:1em;'>
Touch screen support is still experimental. There might be issues with either the module, or due to hardware limitations. Right now I cannot recommend that anyone buys a touch capable screen or IR touch frame for Material Plane, it is probably better to wait until this has been tested more extensively.<br>
<br>
Touch screen functionality is broken in Foundry v11.
</p>
</div>

Material Foundry allows you to use a touch screen to move physical miniatures and have tokens in Foundry follow this movement.

The table of contents on the left is ordered in a way that you should start from the top and move your way down, but below you will find a short description of the steps you will need to take to get started:

1. [Make sure you know what the requirements are for using Material Plane](requirements.md)
2. [Consider the limitations](limitations.md)
3. [Install and configure the VTT module](Foundry/foundryInstall.md)
4. [Learn how to properly use the module](usage.md)

If you encounter any bugs or wish to request new features, please contact me on Discord (@materialfoundry/@Cris) or post an issue on [GitHub](https://github.com/MaterialFoundry/MaterialPlane/issues).<br>
Consider joining the [Material Foundry Discord Server](https://discord.com/invite/3hd4G6TkmA).

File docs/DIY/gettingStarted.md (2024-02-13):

# Getting Started
The Material Plane DIY hardware is one of the hardware options for Material Plane to track minis on a display.<br>
You will have to assembly everything yourself. If you can't or don't want to do this, consider buying the [pre-build production hardware](../Production/gettingStarted.md), which has some other advantages over the DIY hardware. For a full comparison between the various mini-tracking options, please read the [hardware comparison](../hardwareComparison.md) page.

The table of contents on the left is ordered in a way that you should start from the top and move your way down, but below you will find a short description of the most important steps you will need to take to get started:

1. [Make sure you know what the requirements are for using Material Plane](requirements.md)
2. [Figure out what kind of sensor version you want to build](hardwareOverview.md)
3. Build a '[DIY-Full](BuildInstructions/sensorFull.md)' or '[DIY-Basic](BuildInstructions/sensorBasic.md)' sensor
4. [Build one or more bases](BuildInstructions/base.md)
5. [Upload/update the sensor firmware](Updating/sensorUpdating.md)
6. [Figure out the optimal sensor mounting method and position](SensorPositioning/sensorMounting.md)
7. [Connect the sensor to your WiFi network](SensorConfiguration/sensorConnecting.md)
8. [Configure the sensor](SensorConfiguration/sensorSettings.md)
9. [Install and configure the VTT module](Foundry/foundryInstall.md)
10. [Calibrate the sensor](calibration.md)
11. [Learn how to properly use the module](usage.md)

Please check the [troubleshooting](troubleshooting.md) page if you run into any issues.

If you encounter any bugs or wish to request new features, please contact me on Discord (@materialfoundry/@Cris) or post an issue on [GitHub](https://github.com/MaterialFoundry/MaterialPlane/issues).<br>
Consider joining the [Material Foundry Discord Server](https://discord.com/invite/3hd4G6TkmA), and join my [Patreon](https://www.patreon.com/materialfoundry) if you wish to financially support me and this project.

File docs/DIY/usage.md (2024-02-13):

# Mini Placement

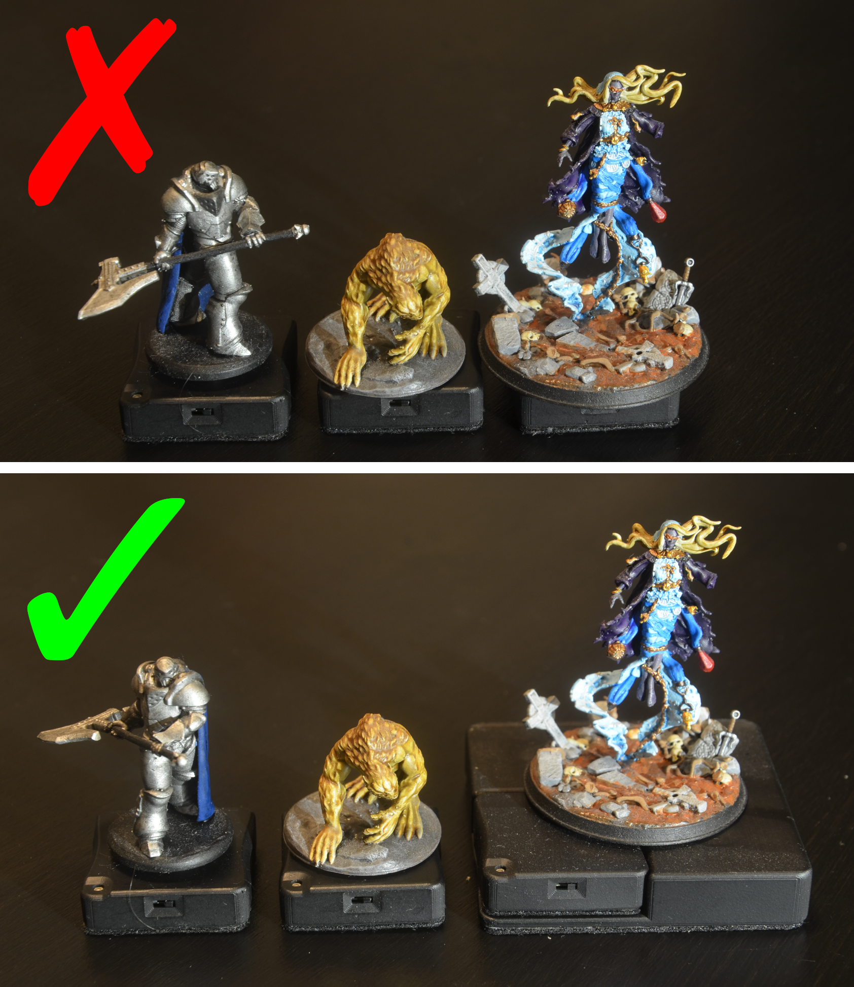
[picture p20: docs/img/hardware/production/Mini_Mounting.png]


When mounting a mini on a base, there is one important thing to remember: there needs to be line-of-sight between the infrared LED and the sensor. There are multiple ways in which the placement of the mini can affect this.

The image on the right shows 3 minis, with incorrect placement at the top and correct placement at the bottom.<br>
From left to right:

* The weapon of the mini is directly above the infrared LED. This means that in most situations the sensor will have a hard time detecting the base. This can be solved by rotating the mini.
* The base of the mini blocks the infrared LED, so the sensor cannot detect it. This can be solved by moving the mini a bit.
* The mini is too big for the base. There is no good way to mount it while keeping the infrared LED visible to the sensor. There is currently no suitable DIY solution for this.

# Orientation and Holding of Bases

During the [calibration procedure](calibration.md) you had to keep the orientation of the base constant relative to the display, for example by keeping the LED in the top-right. When using the base during gaming you have to stick to this orientation, so rotating the base is not possible. You can, of course, rotate the mini on top of the base.

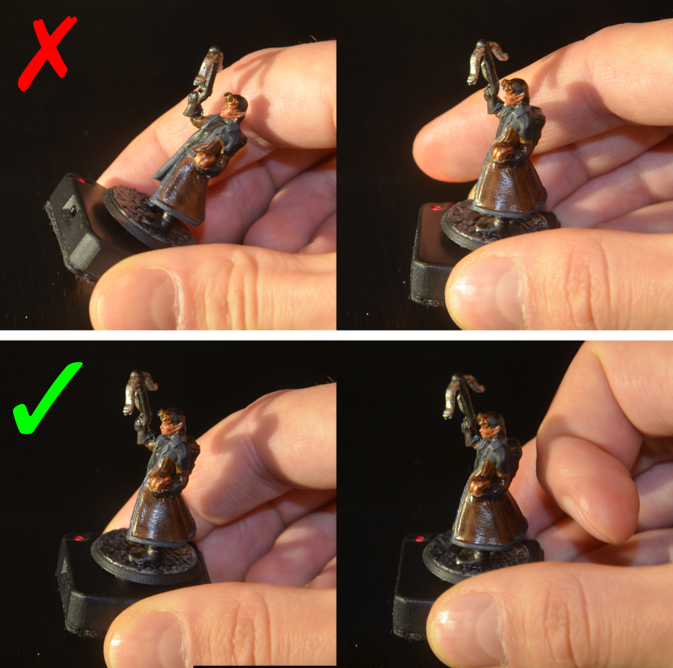
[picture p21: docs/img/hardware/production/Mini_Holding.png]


When moving bases, you should try to keep them as horizontal as possible. If the base is held at an angle, the relative light emission of the base (so from the perspective of the sensor) is reduced, and if the angle is too big, the sensor will not be able to detect the base.<br>
An exception to this is if the base is located near the edge of the display. In this case, it can be helpful to angle the base towards the sensor.

Make sure your finger or any other object does not obscure the LED to prevent line of sight between the LED and sensor. Because the base is activated by touching one of its sides, this will usually not be an issue.

Take a look at the image on the right, which demonstrates these 2 problems, with the upper images showing the incorect way and the lower images the correct way of holding bases.<br>
From left to right:

* Base held at too much of an angle. Reduce the angle to make it easier for the sensor to detect the base.
* Index finger too close to the infrared LED, which might block the line-of-sight between the LED and sensor. Hold the base with the thumb and index finger, or move the index finger away.

# Token Detection
For the DIY hardware, token detection is done using the location of the base. Whenever a base is moved, Material Plane checks if there are any tokens close enough. If there are, it will pick the nearest (that is allowed to be moved) and move that token.<br>
Potential issues are that if any interruption occurs, the token might be dropped, and it can result in the wrong token being moved if multiple tokens are close to each other.

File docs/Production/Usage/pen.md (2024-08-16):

## Pen Activation
The pen is activated whenever one of its buttons are pressed, and it will stay activated for a set amount of time after all buttons have been released. By default this timeout is 10 seconds, but this can be configured using Material Companion as explained [here](../basePenConfig.md).

## Holding the Pen
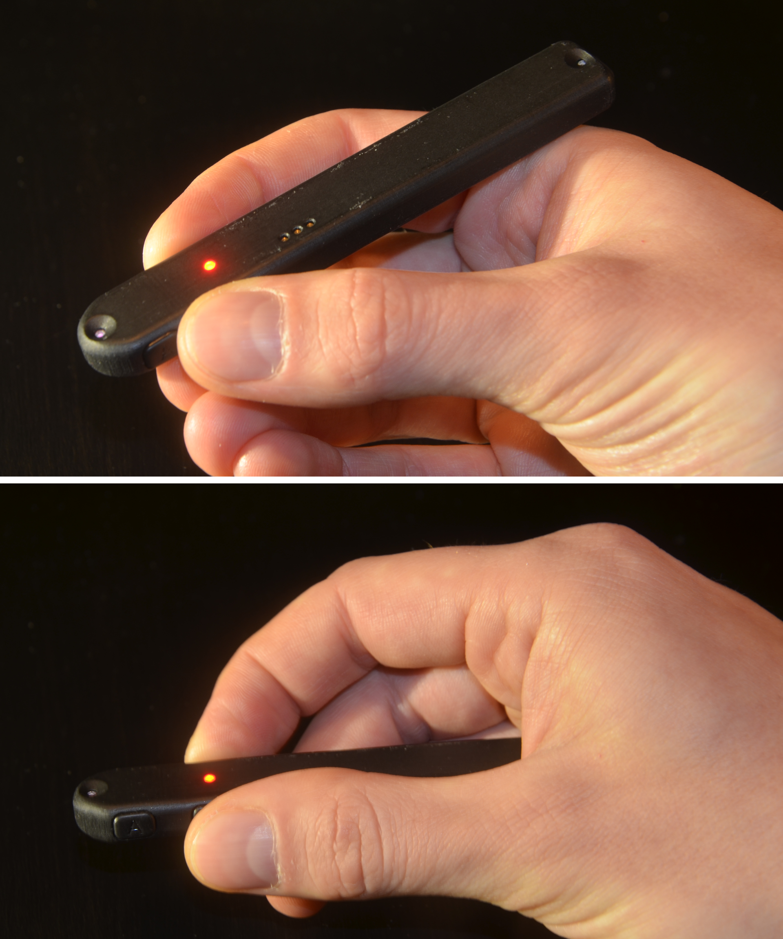
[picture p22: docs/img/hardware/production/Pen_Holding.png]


To use the pen, the side with the LEDs must be facing up, towards the sensor. The side of the pen with the buttons is the front. For the A, C and D buttons, only the front LED needs to be exposed. When pressing the B button both the front and rear LED need to be exposed.

In general, it's best to hold the pen like a normal writing pen: the thumb and index finger hold the pen close to the buttons, with the rear of the pen resing on the part of the hand connecting the thumb and index finger, see the top image on the right.

Alternatively, the pen would be held as shown in the lower image on the right. While this can be more comfortable in some situations, you will not be able to use the function assigned to the B button, since the rear LED is blocked by the hand.

## B Button
The B button is special, because it enables both the front and rear LEDs. This means that the orientation of the pen can be determined.<br>
This is used for rotating things. For example, when using the 'Token' function, you can press B and rotate the pen to rotate a token.

## C Button
The C button is reserved for interacting with the pen menu. Pressing that button will always open the menu, regardless of the mode.

## Pen Menu
By pressing the C button the pen menu will open, it will automatically close when the pen is no longer used. Here, you can select the function of the pen. You select the function using either the C or D button. You can move the menu around by pressing and holding the center (Material Foundry logo) using the C or D button.

You can enable an info display by pressing the info button in the pen menu. This info display displays the current mode and the function of each button.

### Inner circle
The inner circle of the pen menu sets the mode of the pen. The 'Drawings', 'Templates' and 'Macros' modes will open a secondary ring of options.<br>
The following table gives a summary of all options of the pen menu. 

| Mode | Icon | A Button | B Button | D Button |
|--- |--- |--- |--- |--- |
| Canvas | arrow-pointer-solid | Pan canvas | Zoom canvas | Click canvas | 
| Token | user-solid | Deselect token | Rotate token | Move token |
| Ruler | ruler-solid | Undo last segment | Clear ruler | Start ruler/new segment |
| Target | bullseye-solid | Remove all targets| - | Target token |
| Drawings | pencil-alt-solid | Move drawing | Rotate drawing | Draw shape |
| Templates | ruler-combined-solid  | Move tempalate | Rotate template | Draw template |
| Macros | arrow-pointer-solid | User configurable | User configurable | User configurable |
| Info | circle-info-solid | - | - | - |

### Canvas
The canvas mode allows some basic interaction with the canvas, such as panning or zooming the canvas with the A and B buttons, respecivetly.<br>
The D button will click on the canvas and can be used for things like opening doors.

| A Button | B Button | D Button |
|--- |--- |--- |
| Pan canvas | Zoom canvas | Click canvas | 

### Token
The token mode will manipulate tokens.<br>
Tokens can be moved by pressing and holding the D button. They can be rotated by pressing the B button and rotating the pen, and tokens can be deselected with the A button.

| A Button | B Button | D Button |
|--- |--- |--- |
| Deselect token | Rotate token | Move token | 

### Ruler
Distances can be measured using the ruler mode.<br>
Start a measurement by pressing the D button. Using the D button a new ruler segment is created, the A button removes the last segment, and using the B button you can clear the ruler.

| A Button | B Button | D Button |
|--- |--- |--- |
| Undo last segment | Clear the ruler | Start ruler/new segment | 

### Target
Press the D button to target a token and the A button to remove all targets.

| A Button | B Button | D Button |
|--- |--- |--- |
| Remove all targets| - | Target token | 

### Drawings
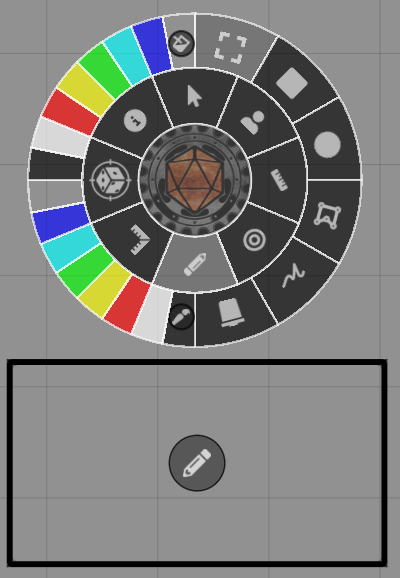
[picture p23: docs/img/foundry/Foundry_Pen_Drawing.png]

With the drawings mode you can place or edit drawings on the canvas.<br>
On the left of the pen menu there are 2 sets of colors. The top-left quadrant sets the fill color of the drawing, while the bottom-left quadrant sets the line color of the drawing.

A pencil icon will be drawn for each drawing on the canvas, this is to indicate the 'target' point for each drawing when trying to edit it using the 'Select' mode.

| Mode | Icon | A Button | B Button | D Button |
|--- |--- |--- |--- |--- |
| Select | expand-solid | Move drawing | Rotate drawing | Resize drawing | 
| Rectangle/Ellipse/Freehand | square-solid/circle-solid/signature-solid | - | - | Draw shape |
| Polygon | draw-polygon-solid  | - | Undo last segment | Place new segment |
| Clear | trash-solid | - | - | Remove drawing |

### Templates
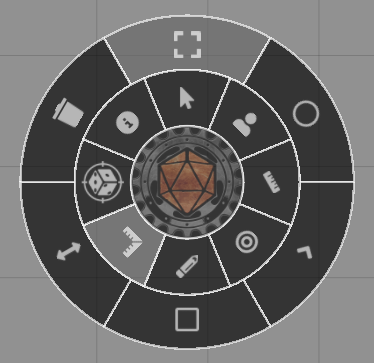
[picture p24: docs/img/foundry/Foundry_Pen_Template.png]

With the template mode you can place or edit templates on the canvas.<br>

| Mode | Icon | A Button | B Button | D Button |
|--- |--- |--- |--- |--- |
| Select | expand-solid | Move template | Rotate template | Resize template | 
| Circle/Cone/Rectangle/Ray | circle-solid/angle-left-solid/square-regular/arrows-left-right-solid | - | - | Draw template |
| Clear | trash-solid | - | - | Remove template |

### Macros
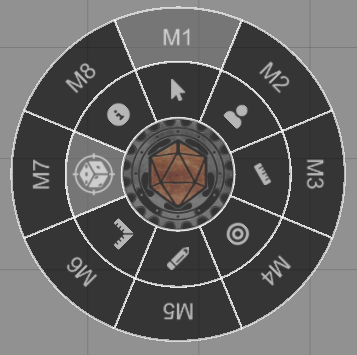
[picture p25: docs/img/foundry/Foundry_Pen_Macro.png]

The macro mode allows for customized and more complex pen behavior.<br>
<br>
You can have up to 8 groups of macros (M1 - M8), where each macro group can have one or more macros assigned to each button and button  mode (press/release/hold).<br>
Macros can be assigned to buttons and button modes from the '[Pen Setup](../Foundry/foundryConfig.md#pen-setup)' tab in the module configuration.<br>
<br>
Macros have access to the following variables:

| Variable | Description |
|--- |--- |
|scope.button | Button that is being pressed  |
|scope.buttonMode | Mode of the button that is being pressed (press/release/hold) |
|scope.coordinates | X and Y coordinates of the pen (e.g. scope.coordinates.x) |
|scope.coordinates2 | X and Y coordinates of the second infrared LED of the pen when the B button is pressed |
|scope.angle | Angle (in degrees) of the pen when the B button is pressed |
|scope.length | Apparent length (in pixels) of the pen when the B button is pressed. This is essentially the distance between scope.coordinates and scope.coordinates2. |
|scope.id | Id of the pen |
|scope.raw | Raw data of the pen point(s), see below |

Raw data:
```js 
scope.raw = [
    {
        //point 0
        number: 0; //number of the point
        area: 11; //area of the point
        avgBrightness: 221; //average brightness of the point
        maxBrightness: 253; //maximum brightness of the point
        x: 1135.542; //unscaled x-coordinate of the point
        y: 1723.461; //unscaled y-coordinate of the point
    },{
        //point 1
    }  
]
```

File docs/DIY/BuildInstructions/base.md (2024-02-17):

# Base Build Instructions

{% include 'diyDisclaimer.md' %}

This page discusses the fabrication of the DIY bases.<br>
Discussed on this page are the required tools, materials and parts you need, a sourcing guide for 3D prints and electrical components, and the complete build instructions.

# Requirements
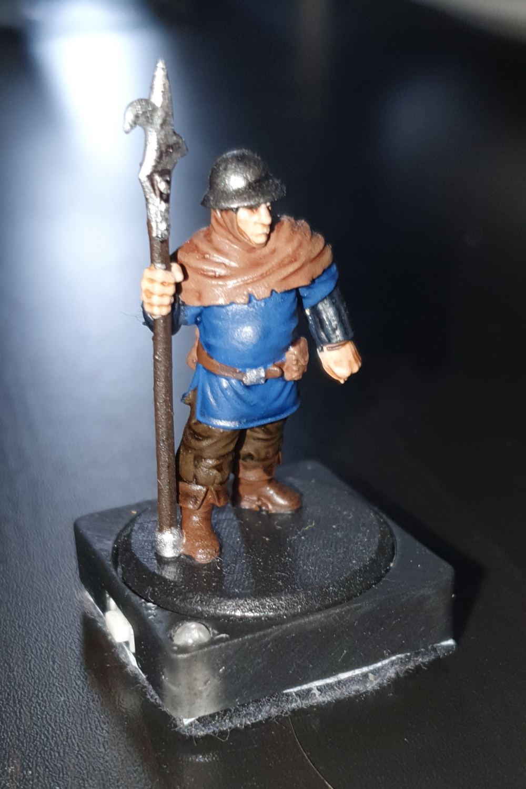
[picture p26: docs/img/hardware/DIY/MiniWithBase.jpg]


## Required Tools

* Soldering iron + solder
* Wire cutter
* Wire stripper
* Scissors
* Superglue

## Bill of Materials

* [3D printed parts](https://github.com/MaterialFoundry/MaterialPlane_Models) (see below)
* 1x 3mm infrared LED (940nm)
* 1x Microswitch
* 1x CR2032 battery
* Felt that's big enough to cover the base (with adhesive pre-attached, or add double-sided tape)

## Sourcing Parts

#### 3D Prints

To build the base you will to print the base enclosure, which you can download [here](https://github.com/MaterialFoundry/MaterialPlane_Models). There are currently 2 variants:

* Normal: Has a cavity into which the round base of a mini can fit
* Flat: Has a flat top (no cavity)

A resin printer is recommended for these parts, but FDM might also work if your printer is properly tuned (you might need to use a smaller nozzle).

If you do not own a 3D printer, and you do not know anyone who can print for you, you could consider one of the following print services:

* [3D Hubs](https://www.hubs.com/)
* [Shapeways](https://www.shapeways.com/)
* [i.Materialize](https://i.materialise.com/en)

### Electrinic Components

| Supplier | IR LED | Microswitch |
|---|---|---|
| Mouser (US) | [link](https://eu.mouser.com/ProductDetail/Kingbright/WP710A10F3C?qs=jBF9H7RTBaTxk2AdjwNryg%3D%3D) | [link](https://eu.mouser.com/ProductDetail/CK/RS032G05A3SMRT?qs=Gufeu08L%2Fl3gq3su6e3ufw%3D%3D) |
| Digikey (US) |[link](https://www.digikey.com/en/products/detail/inolux/INL-3AHIR30/10384806) <br> [link](https://www.digikey.com/en/products/detail/sunled/XTNI11W/13559383) | [link](https://www.digikey.com/en/products/detail/w%C3%BCrth-elektronik/434121050816/5209081) <br> [link](https://www.digikey.com/en/products/detail/w%C3%BCrth-elektronik/434111050826/5209074) |
| Botland (PL) | [link](https://botland.store/led-ir-infrared/869-ir-transmitter-vslb3940-3mm-940nm-5904422300975.html) | [link](https://botland.store/tact-switch/11104-tact-switch-3x6mm-5mm-smd-5pcs-5904422307585.html) |

# Instructions
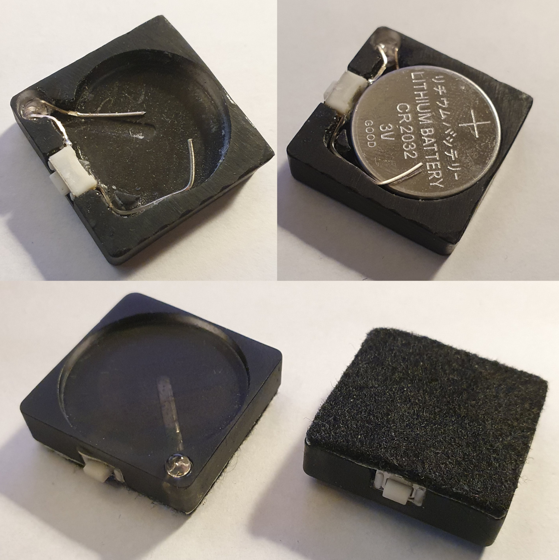
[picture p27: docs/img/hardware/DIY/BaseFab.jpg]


1. Glue the switch in place (see the image below for positioning). Try to push it as far to the outside as possible and make sure it is flush with the top of the 3D print.
2. The LED has a positive and negative lead which can be distinguised by the length, where the positive lead is longer. Push the LED into its cavity with the positive (longer) lead to the switch side.
3. Bend the negative (shorter) lead so it fits in the groove, and cut it to size so it's approximately the length of the groove.
4. Bend the positive (longer) lead so it makes contact with the nearest contact on the switch.
5. Solder the lead to that contact.
6. Cut off any excess of the LED lead.
7. Solder the excess you just cut off to the other contact of the switch.
8. Bend it in such a way that it passes through the channel towards the center area, bent upwards.
9. Insert the CR2032 battery, positive side up, make sure the lead coming from the switch touches the battery (either the side or top).
10. Attach the felt and cut to size.

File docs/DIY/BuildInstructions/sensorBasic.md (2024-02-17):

# Basic Sensor Build Instructions

{% include 'diyDisclaimer.md' %}

This page discusses the fabrication of the basic DIY sensor. If you are not sure whether you want to build the full or basic sensor, please head over to the [hardware overview](../hardwareOverview.md).<br>
Discussed on this page are the required tools, materials and parts you need and the build instructions.

## Before You Get Started
The basic sensor build requires a compatible ESP32 board. Almost any ESP32 or ESP32-S3 board is compatible. It will need to be dual core (so no ESP32-SOLO based boards) and based on whether you have an ESP32 or ESP32-S3, you will need to make sure that the following pins are available on the board:

| Board | Pins |
|---|---|
| ESP32 | 21 & 22 |
| ESP32-S3  | 8 & 9 |

### Compatible Boards
For Material Plane, there is no noticable difference between an ESP32 or ESP32-S3, so pick the one that you can source or the one that is cheapest.<br>
Below is an incomplete list of boards that <i>should</i> be compatible.

| ESP32 | ESP32-S3 |
|---|---|
| ESP32-DevKitC | ESP32-S3-DevKitC |
| ESP32-PicoKit | Arduino Nano ESP32 |
| Wemos LOLIN32 | Wemos S3 (also the Mini and Pro)  |
| FireBeetle ESP32 | LilyGo T7-S3 |
| <i>And many more</i> | <i>And many more</i> |

### Things to Avoid
When looking through the product listing, make sure you don't see any of the following terms:

* ESP32-S2
* ESP32-Cx (can be C2, C3 or C6)
* ESP32-H2
* ESP-WROOM-02
* ESP8266
* Solo
* Zigbee

## Requirements

### Required Tools

* Soldering iron + solder
* Wire cutter
* Wire stripper

### Bill of Materials

* 3D printed parts
* An ESP32 or ESP32-S3
* DFRobot SEN0158

### Sourcing Parts

<b>Please note that the links below are a suggestion only and there may be mistakes. It is your own responsibility to make sure the part is compatible.<br>
If you find an incompatible part or a dead/incorrect link, please contact me.</b>

| Supplier | ESP32/ESP32-S3 | DFRobot SEN0158 |
|---|---|---|
| Mouser (US) | [ESP32-DevKitC](https://eu.mouser.com/ProductDetail/Espressif-Systems/ESP32-DevKitC-VIB?qs=w%2Fv1CP2dgqqYaiigtkDvQw%3D%3D)<br>[ESP32-S3-DevKitC](https://eu.mouser.com/ProductDetail/Espressif-Systems/ESP32-S3-DevKitC-1U-N8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) | [link](https://eu.mouser.com/ProductDetail/DFRobot/SEN0158?qs=lqAf%2FiVYw9hCccCG%252BpzjbQ%3D%3D) |
| Digikey (US) | [ESP32-PicoKit](https://www.digikey.com/en/products/detail/espressif-systems/ESP32-PICO-KIT-1/21572663) <br> [ESP32-S3-DevKitC](https://www.digikey.com/en/products/detail/espressif-systems/ESP32-S3-DEVKITC-1-N8R2/15199627) | [link](https://www.digikey.com/en/products/detail/dfrobot/SEN0158/7087147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) |
| RobotShop (US) | [FireBeetle ESP32](https://www.robotshop.com/products/firebeetle-esp32-iot-microcontroller) <br> [Arduino Nano ESP32](https://www.robotshop.com/products/arduino-nano-esp32-with-headers) | [link](https://www.robotshop.com/en/ir-tracking-camera.html) |
| TinyTronics (NL) | [ESP32 Board](https://www.tinytronics.nl/shop/en/development-boards/microcontroller-boards/with-wi-fi/esp32-wifi-and-bluetooth-board-cp2102) <br> [Wemos LOLIN32](https://www.tinytronics.nl/shop/en/development-boards/microcontroller-boards/with-wi-fi/wemos-lolin32-esp32-cp2104) | [link](https://www.tinytronics.nl/shop/en/sensors/optical/infrared/dfrobot-gravity-ir-positioning-camera) |
| OpenCircuit (NL) | [FireBeetle ESP32](https://opencircuit.shop/product/firebeetle-esp32-e-iot-microcontroller) <br> [Lilygo T7-S3](https://opencircuit.shop/product/lilygo-t7-s3-esp32-s3-development-board-wifi) | [link](https://opencircuit.shop/product/gravity-ir-positioning-camera-for-arduino) |
| Gotronic (FR) | [NodeMCU ESP32](https://www.gotronic.fr/art-module-nodemcu-esp32-28407.htm) <br> [Seeed Studio XIAO ESP32S3](https://www.gotronic.fr/art-carte-xiao-esp32s3-36954.htm) | [link](https://www.gotronic.fr/art-camera-ir-de-positionnement-sen0158-22705.htm) |
| Botland (PL) | [ESP32-DevKitC](https://botland.store/esp32-wifi-and-bt-modules/8893-esp32-wifi-bt-42-platform-with-module-5904422337438.html) <br> [ESP32-S3 DevKit](https://botland.store/esp32-wifi-and-bt-modules/23340-esp32-s3-dev-kit-n8r8-development-board-wifi-bluetooth-without-connectors-waveshare-24363.html) | [link](https://botland.store/arduino-rpi-cameras/19901-gravity-ir-positioning-camera-for-arduino-dfrobot-sen0158--5903351246330.html) |
| DFRobot (CN) | [FireBeetle ESP32](https://www.dfrobot.com/product-1590.html) <br> [FireBeetle 2 ESP32-S3](https://www.dfrobot.com/product-2676.html) | [link](https://www.dfrobot.com/product-1088.html) |

## Instructions
The instructions for the basic sensor are really simple.<br>
Solder the wires of the DFRobot SEN0158 to the following pins:

| Wire Color | Function  | ESP32 pin | ESP32-S3 pin |
|---|---|---|---|
| Red | Power | 3V3 | 3V3 |
| Black | Ground | GND | GND |
| Yellow | SDA | 21 | 8 |
| Green | SCL | 22 | 9 |

That's it. Any further additions to the sensor are up to you.

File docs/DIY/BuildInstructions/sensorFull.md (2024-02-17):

# Full Sensor Build Instructions

{% include 'diyDisclaimer.md' %}

This page discusses the fabrication of the full DIY sensor. If you are not sure whether you want to build the full or basic sensor, please head over to the [hardware overview](../hardwareOverview.md).<br>
Discussed on this page are the required tools, materials and parts you need, a sourcing guide for 3D prints and electrical components, and the complete build instructions.

## Before You Get Started
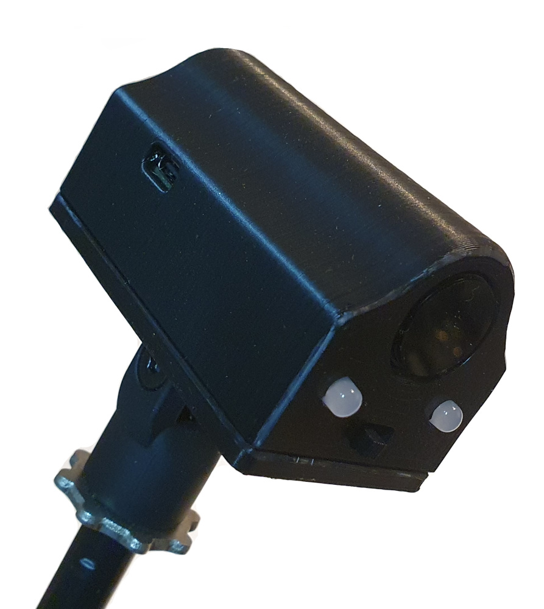
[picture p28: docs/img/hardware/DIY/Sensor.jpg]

The full sensor build requires one of the following ESP32 boards:

* TinyPico V1 or V2 (with micro-USB port, discontinued)
* TinyPico V3 (with USB-C port)
* TinyS3

For Material Plane, there is no noticable difference between these variants, so pick the one that you can source or the one that is cheapest.
In these build instructions there will be variant-specific things you need to do (such as which pins to connect everything to). In these cases, there will be a table to give these differences. Please take note of which variant you have so you don't make any mistakes.

There are variants of these board with no on-board antenna, <b>do not get one of those</b>.

## Requirements

### Required Tools

* Soldering iron + solder
* Wire cutter
* Wire stripper
* Knife
* Hot glue gun or superglue
* (Optional, but recommended) Electrical tape or heat shrink
* (Optional) M3 threading tool

### Bill of Materials

* [3D printed parts](https://github.com/MaterialFoundry/MaterialPlane_Models) (see below)
* A TinyPICO V1, V2 or V3, or a TinyS3
* DFRobot SEN0158
* 2x 5mm Red/Green or RGB <b>common cathode</b> LED
* 2x 180 Ohm wired resistor (200 or 220 Ohm will also work fine)
* 1x 12 KOhm wired resistor (TinyPICO only)
* 1x 22 KOhm wired resistor (TinyPICO only)
* 1x SPDT Slide Switch (approx 6x20mm)
* 1x Li-Ion battery (max size: 34x53x11mm)
* 9x M3x10mm countersunk bolts
* 1x M5x22mm bolt
* 1x M5 nut

### Sourcing Parts

#### 3D Prints

To build the sensor you will need one of each of the following parts (only the 'Sensor Main Body' is different), which you can download [here](https://github.com/MaterialFoundry/MaterialPlane_Models):

|Part| TinyPICO V1/V2 | TinyPICO V3 | TinyS3 |
|----|---|---|---|
| Sensor Main Body | MainBody.stl | MainBody_USBC.stl | MainBody_USBC.stl |
| Sensor Lid | Lid.stl | Lid.stl | Lid.stl |
| Controller Bracket | ControllerBracket.stl | ControllerBracket.stl | ControllerBracket.stl |
| Sensor Bracket | SensorBracket.stl | SensorBracket.stl | SensorBracket.stl | 
| Microphone Mount | MicstandMount.stl | MicstandMount.stl | MicstandMount.stl | 

All parts, except for the sensor main body can be printed flat on the 3D printer's bed. The sensor main body was designed to be printed on it's front (the side with the holes).

Recommended printer parameters:

| | |
|---|---|
| Material | PLA, PLA+, PETG or ABS |
| Nozzle | 0.4 - 0.8mm |
| Layer Height  | 0.2mm |
| Supports | None |

If you do not own a 3D printer, and you do not know anyone who can print for you, you could consider one of the following print services:

* [3D Hubs](https://www.hubs.com/)
* [Shapeways](https://www.shapeways.com/)
* [i.Materialize](https://i.materialise.com/en)

#### Electronic Components

<b>Please note that the links below are a suggestion only and there may be mistakes. It is your own responsibility to make sure the part is compatible.<br>
If you find an incompatible part or a dead/incorrect link, please contact me.</b>

| Supplier | TinyPICO/TinyS3 | DFRobot SEN0158 | LEDs  | Resistors | Switch | Battery |
|---|---|---|---|--|--|--|
| Mouser (US) | [TinyPICO V3](https://nl.mouser.com/ProductDetail/Adafruit/5750?qs=mELouGlnn3eyxZ0u5J6K4g%3D%3D)<br>[TinyS3](https://nl.mouser.com/ProductDetail/Unexpected-Maker/TS3-01?qs=Z%252BL2brAPG1LZhhN9kgkCAg%3D%3D) | [link](https://eu.mouser.com/ProductDetail/DFRobot/SEN0158?qs=lqAf%2FiVYw9hCccCG%252BpzjbQ%3D%3D) | [RG](https://nl.mouser.com/ProductDetail/Lite-On/LTL-30EFJ?qs=cXLtXeiLR4oiGhB%2FiN7QdQ%3D%3D) [RG](https://nl.mouser.com/ProductDetail/Kingbright/WP59SURKCGKW?qs=DkZGzo4b%252BTLYvNaeWp2TSg%3D%3D) <br> [RGB](https://nl.mouser.com/ProductDetail/Inolux/HV-5RGB60?qs=qSfuJ%252Bfl%2Fd7yi2o6d75%2FlQ%3D%3D) [RGB](https://nl.mouser.com/ProductDetail/Kingbright/WP154A4SUREQBFZGW?qs=w3%252Bcv6FlocrIOROaa2rdEg%3D%3D) | [180R](https://nl.mouser.com/ProductDetail/YAGEO/CFR-12JR-52-180R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) [180R](https://nl.mouser.com/ProductDetail/YAGEO/CFR-12JB-52-180R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) <br> [12K](https://nl.mouser.com/ProductDetail/YAGEO/CFR-12JB-52-12K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) [12K](https://nl.mouser.com/ProductDetail/YAGEO/CFR-25JR-52-12K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) <br> [22K](https://nl.mouser.com/ProductDetail/YAGEO/CFR-25JR-52-22K?qs=sGAEpiMZZMsPqMdJzcrNwsJljJEG6Yukd6qoZEzq39o%3D) [22K](https://nl.mouser.com/ProductDetail/YAGEO/CFR-25JR-52-22K?qs=sGAEpiMZZMsPqMdJzcrNwsJljJEG6Yukd6qoZEzq39o%3D) | [link](https://nl.mouser.com/ProductDetail/E-Switch/EG1201?qs=HKd%2Fp3M7KlXO9na9WUJSSA%3D%3D) | |
| Digikey (US) | [TinyPICO V2](https://www.digikey.com/en/products/detail/adafruit-industries-llc/5029/14307381) <br> [TinyS3](https://www.digikey.com/en/products/detail/adafruit-industries-llc/5398/16499316) | [link](https://www.digikey.com/en/products/detail/dfrobot/SEN0158/7087147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) | [RG](https://www.digikey.com/en/products/detail/american-bright-optoelectronics-corporation/BL-BUBGE204/9678166) [RG](https://www.digikey.com/en/products/detail/kingbright/WP59SURKCGKW/2785960) <br> [RGB](https://www.digikey.com/en/products/detail/nte-electronics-inc/NTE30156/11646510) [RGB](https://www.digikey.com/en/products/detail/inolux/HV-5RGB60/7604616) | [180R](https://www.digikey.com/en/products/detail/stackpole-electronics-inc/CF14JT180R/1741307) [180R](https://www.digikey.com/en/products/detail/yageo/MFR-25FBF52-180R/9138058) <br> [12K](https://www.digikey.com/en/products/detail/stackpole-electronics-inc/CF14JT12K0/1741282) [12K](https://www.digikey.com/en/products/detail/stackpole-electronics-inc/CFM14JT12K0/1742076) <br> [22K](https://www.digikey.com/en/products/detail/stackpole-electronics-inc/CF14JT22K0/1741350) [22K](https://www.digikey.com/en/products/detail/stackpole-electronics-inc/RNMF14FTC22K0/2617315) | [link](https://www.digikey.com/en/products/detail/cit-relay-and-switch/MS1201L5B/21619487) <br> [link](https://www.digikey.com/en/products/detail/e-switch/EG1201/101720) | [link](https://www.digikey.com/en/products/detail/sparkfun-electronics/PRT-18286/14302550) <br> [link](https://www.digikey.com/en/products/detail/jauch-quartz/LP103048JU-PCM-2-WIRES-70MM/9560992) |
| RobotShop (US) | | [link](https://www.robotshop.com/en/ir-tracking-camera.html) | [RGB](https://www.robotshop.com/products/sfe-triple-output-led-rgb) | | | |
| TinyTronics (NL) | [TinyPICO V3](https://www.tinytronics.nl/shop/en/development-boards/microcontroller-boards/with-wi-fi/unexpected-maker-tinypico-v3-esp32-development-board-usb-c) | [link](https://www.tinytronics.nl/shop/en/sensors/optical/infrared/dfrobot-gravity-ir-positioning-camera) | [RGB](https://www.tinytronics.nl/shop/en/components/leds/leds/rgb-led-5mm-diffuse-common-cathode) | | | |
| OpenCircuit (NL) | | [link](https://opencircuit.shop/product/gravity-ir-positioning-camera-for-arduino) | [RGB](https://opencircuit.shop/product/rgb-5mm-leds-common-cathode-10-stuks) | [180R](https://opencircuit.shop/product/180%CF%89-metal-film-resitor-1-4w-10-pieces) <br> [12K](https://opencircuit.shop/product/12k%CF%89-metal-film-resitor-1-4w-10-pieces) <br> [22K](https://opencircuit.shop/product/22k%CF%89-metal-film-resistor-1-4w-10-pieces) | | |
| Gotronic (FR) | | [link](https://www.gotronic.fr/art-camera-ir-de-positionnement-sen0158-22705.htm) | [RGB](https://www.gotronic.fr/art-led-rgb-5-mm-rgb5-dif-2099.htm) | [180R](https://www.gotronic.fr/art-10-resistances-1-4w-180-8486-349.htm) <br> [12K](https://www.gotronic.fr/art-10-resistances-1-4w-12k-8486-2582.htm) <br> [22K](https://www.gotronic.fr/art-10-resistances-1-4w-22k-8486-2585.htm) | | [link](https://www.gotronic.fr/art-accu-lipo-3-7-vcc-1000-mah-pr523450-5813.htm) <br> [link](https://www.gotronic.fr/art-accu-lipo-3-7-vcc-1500-mah-thym-bat-37198.htm) |
| Botland (PL) | | [link](https://botland.store/arduino-rpi-cameras/19901-gravity-ir-positioning-camera-for-arduino-dfrobot-sen0158--5903351246330.html) | [RGB](https://botland.store/rgb-led/1667-led-rgb-5mm-matte-common-cathode-5-pcs-5903351244152.html) | [assortment](https://botland.store/resistor-packs/813-set-of-tht-1-4w-resistors-described-2640pcs-5903351241076.html) | | [link](https://botland.store/battery-li-pol-1s-37-v/15626-akyga-li-pol-cell-1500mah-1s-37v-jst-bec-connector-socket-50x34x8mm-5904422324322.html) <br> [link](https://botland.store/battery-li-pol-1s-37-v/12212-akyga-li-pol-1600mah-1s-37v-battery-jst-bec-connector-socket-50x34x9mm-5904422318895.html) |
| DFRobot (CN) | | [link](https://www.dfrobot.com/product-1088.html) | | | | |
| LCSC (CN) | | | | | [link](https://www.lcsc.com/product-detail/Slide-Switches_G-Switch-SS-12F16-G050_C2876006.html)| |
| Unexpected Maker (AU) | [TinyPICO V3](https://unexpectedmaker.com/shop.html#!/TinyPICO/p/577111313/category=154494282) <br> [TinyS3](https://unexpectedmaker.com/shop.html#!/TinyS3/p/577100101/category=154222511) | | | | | |
| Pimoroni (UK) | [TinyPICO V3](https://shop.pimoroni.com/products/tinypico-v2?variant=39285089534035) <br> [TinyS3](https://shop.pimoroni.com/products/tinys3-esp32-s3?variant=39854967881811) | | [RGB](https://shop.pimoroni.com/products/led-rgb-clear-common-cathode?variant=44298388170) | [assortment](https://shop.pimoroni.com/products/resistor-grab-bag?variant=370750519) | | [link](https://shop.pimoroni.com/products/lipo-battery-pack?variant=20429082183) |
| Adafruit (US) | [TinyPICO V3](https://www.adafruit.com/product/5028) <br> [TinyS3](https://www.adafruit.com/product/5398) | | | | | |

## Pinout
While the pin numbers that are used for each variant are stated at each relevant step in the build instructions, you can use the table below as a quick reference.

| | TinyPICO V1/V2 | TinyPICO V3 | TinyS3 |
|---|---|---|---|
| SDA | 21 | 21 | 8 | 
| SCL | 22 | 22 | 9 | 
| LED 1 Red | 26 | 26 | 7 | 
| LED 1 Green | 25 | 25 | 6 |
| LED 2 Red | 15 | 15 | 5 | 
| LED 2 Green | 27 | 27 | 21 |  
| USB Active | 32 | 32 | None (internal) |
| Charge Detect | None (internal) | None (internal) | 1 |

## Instructions

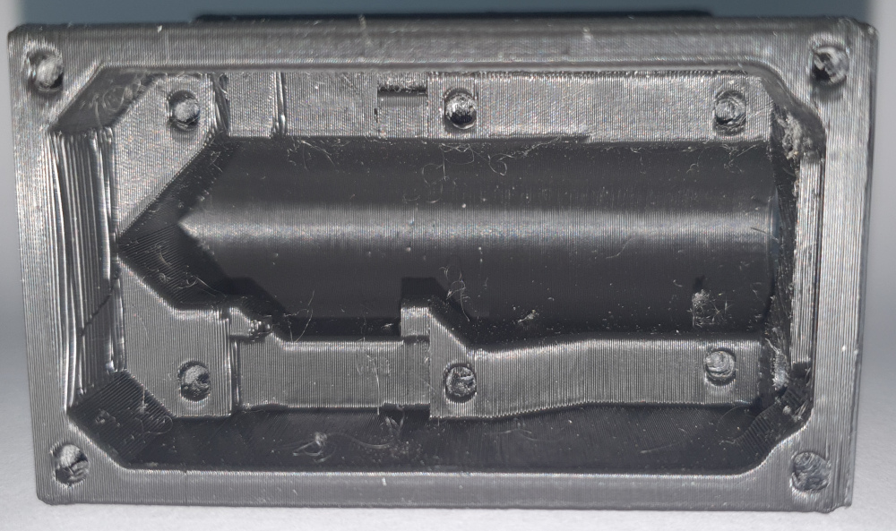
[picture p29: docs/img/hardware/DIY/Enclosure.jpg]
1. Clean the enclosure, and make sure all components fit. Especially the DFRobot SEN0158 and the TinyPICO/TinyS3 might be a tight fit (scroll down see the images for the proper placement and positioning). If necessary, cut away small parts of the enclosure with a sharp knife to make room for the components. You might have to drill out the LED holes with a 5mm drill, if they do not fit.
2. Either use a M3 threading tool to create threads in all holes. Alternatively, grab an M3 bolt, and screw it into all the holes to form the thread. It should give some resistance (and the bolt will get hot, so you might have to let it cool down between holes), but it should be possible without too much problems, if not, predrill the holes with a 2.5mm drill.
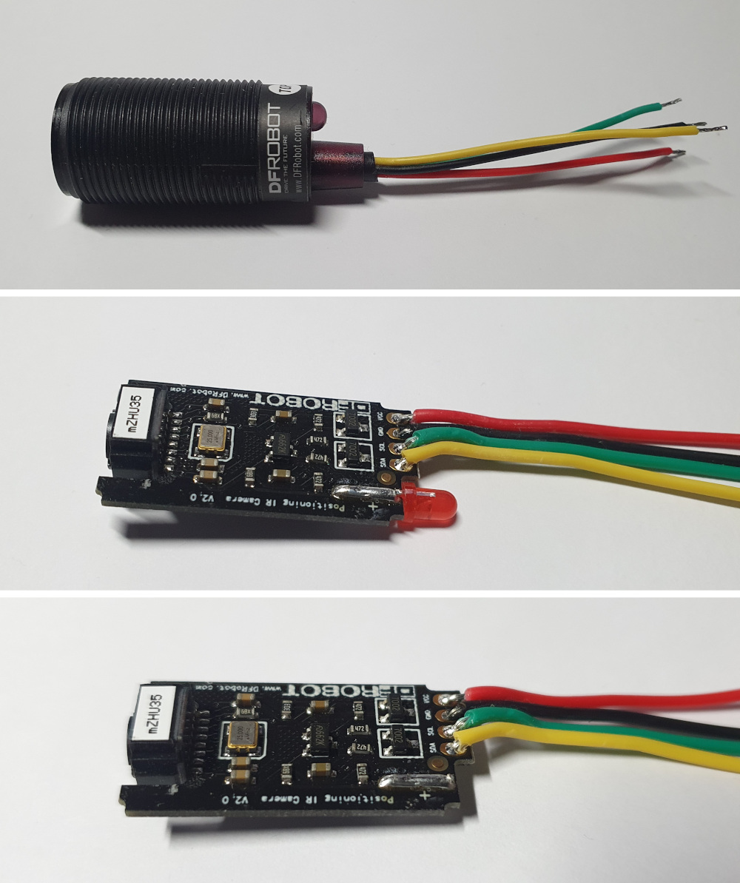
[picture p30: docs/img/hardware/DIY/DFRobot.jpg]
3. Using a wire cutter, cut the length of the cable of the DFRobot SEN0158 to around 5 cm (keep the rest for later), and carefully remove the outer sleeve using a knife. If you choose to remove the LED form the DFRobot SEN0158 (see step 5), it might be easier to remove the outer sleeving after opening the DFRobot SEN0158.
4. Strip a few millimeters off each of the 4 DFRobot SEN0158 wires, and pre-tin them (apply a bit of solder to them).
5. (Optional) Remove the LED inside the DFRobot SEN0158. This will reduce the power consumption by around 20 mA, increasing battery life:
    1. Removing the label.
    2. Pry open the top using a knife (it is glued in place, so it might take some force).
    3. Removing the circuit board.
    4. Desoldering/cut the LED. 
    5. Re-insert the circuit board into its enclosure (note the groove on the far side of the enclosure, into which the circuit board fits). 
    6. Re-apply the label or wrap some tape around the end of the DFRobot SEN0158 to prevent the circuit board from falling out.
6. (<b>TinyS3 only</b>) At the bottom of the board, solder a piece of wire between pin 1 and one of the pads labeled 'CUT TO DISABLE CHRG LED'. You can use a piece of the leads of the LEDs that you will cut in step 8.<br>
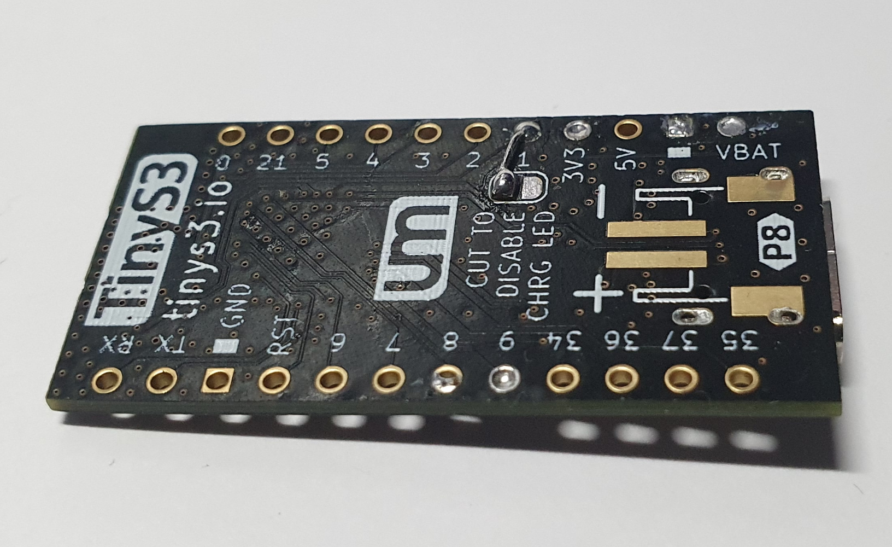
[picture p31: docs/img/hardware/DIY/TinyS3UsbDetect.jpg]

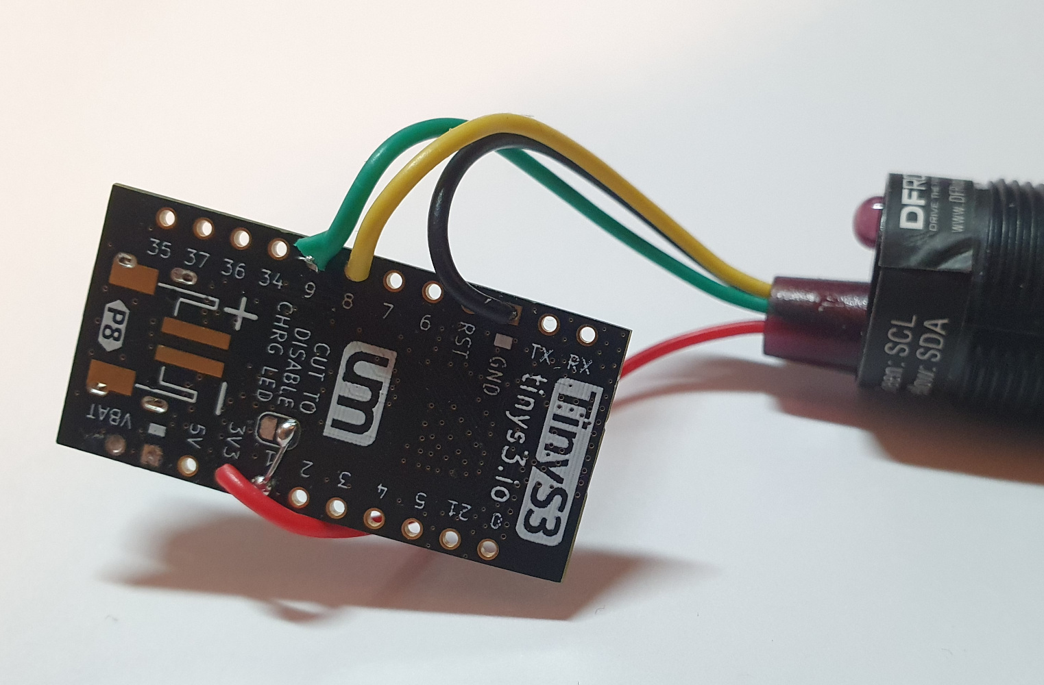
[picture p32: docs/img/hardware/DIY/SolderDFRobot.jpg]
7. Solder the 4 wires from the IR sensor to the TinyPICO/TinyS3:

    | Wire Color    | Function  | TinyPICO pin      | TinyS3 pin        |
    |---------------|-----------|-------------------|-------------------|
    | Red           | Power     | 3V3               | 3V3               |
    | Black         | Ground    | GND (next to RST) | GND (next to RST) |
    | Yellow        | SDA       | 21                | 8                 |
    | Green         | SCL       | 22                | 9                 |

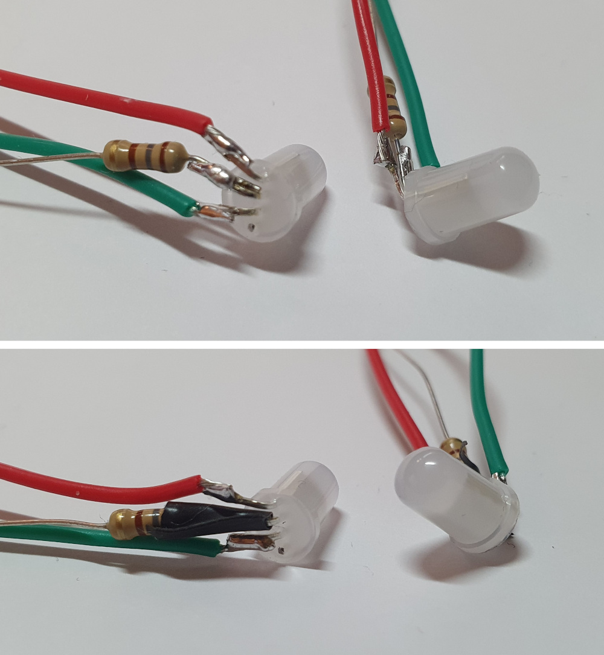
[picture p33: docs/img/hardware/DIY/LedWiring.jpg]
8. Take the 2 LEDs and 2 180 Ohm resistors. The next steps will have to be performed on both LEDs. 
    1. Figure out what each lead of the LED does. Either use the datasheet, or test it by supplying a low voltage (max 5V @ 20mA) between the longest (ground) lead and the others, you could use a coin cell for this. For the RGB LED I used, starting from the shortest lead, it was:

        | Lead Length   | Function  |
        |---------------|-----------|
        | Shortest      | Blue      |
        | Medium        | Green     |
        | Longest       | Ground    |
        | Medium        | Red       |
    
    2. (<b>RGB LEDs only</b>) Cut the lead for the blue LED off as far as possible. The blue will not be used.
    3. Bend all leads to a 90 degree angle.
    4. Cut the longest (ground) lead to a length of approximately 5mm, do the same for one lead of the 180 Ohm resistors.
    5. Solder the 5mm lead of the resistor to the ground lead of the LEDs.
    6. Grab/cut 80mm red and green wires (from the remaining wire of the DFRobot SEN0158), strip a few millimeters of each side and pre-tin them.
    7. Cut the red lead of the LED to a length of approximately 5mm, and solder the red wire to it.
    8. Do the same for the green lead and wire.
    9. (Optionally, but recommended) Apply electrical tape or heat shrink around the lead close to the LED to electrically isolate the leads (to prevent shorts). Do this at least for the ground lead, and optionally for the others.

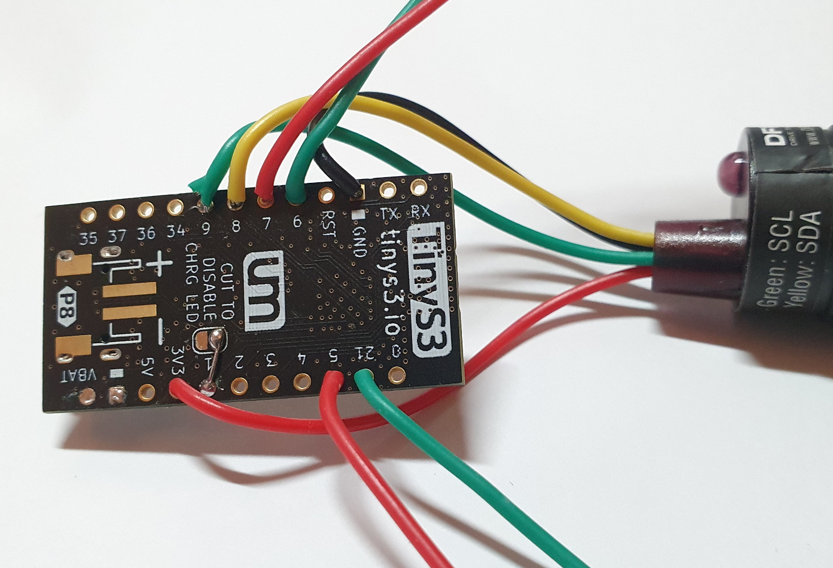
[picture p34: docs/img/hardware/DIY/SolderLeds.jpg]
9. Solder the wires from the LEDs to the TinyPICO/TinyS3 at the following pins:

    | LED   | Wire      | TinyPICO pin  | TinyS3 pin    |
    |-------|-----------|---------------|---------------|
    | 1     | Red       | 26            | 7             |
    | 1     | Green     | 25            | 6             |
    | 2     | Red       | 15            | 5             |
    | 2     | Green     | 27            | 21            |  

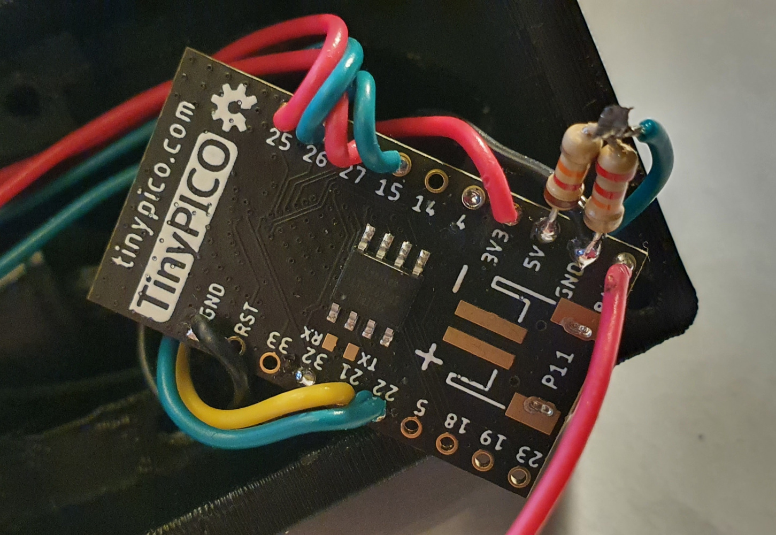
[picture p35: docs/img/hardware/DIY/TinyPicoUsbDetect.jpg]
10. (<b>TinyPICO only</b>) Grab the 12 KOhm and 22 KOhm resistors.
    1. Cut the length of one lead of each resistor to a length of approximately 5mm.
    2. Solder the two 5mm leads together.
    3. Solder the other leg of the 22 KOhm resistor to GND (between 5V and BAT).
    4. Solder the other leg of the 12 KOhm resistor to 5V.
    5. Trim the length of the exposed leads.
    5. Cut a piece of wire to a length of approximately 4 cm (from the remaining wire of the DFRobot SEN0158), strip a few millimeters of each side and pre-tin them.
    6. Solder one side of the wire to the previously soldered connection between the 12 and 22 KOhm resistors, and solder the other side to pin 32.
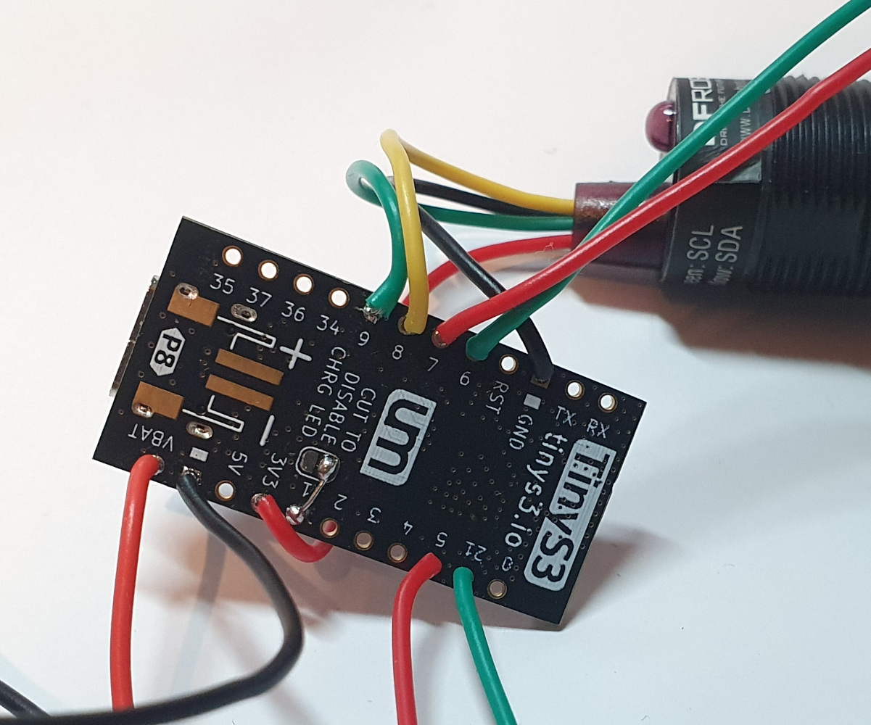
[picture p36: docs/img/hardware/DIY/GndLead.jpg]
11. Cut a piece of black wire to a length of 8 cm (from the remaining wire of the DFRobot SEN0158), strip and pre-tin each side and solder one side to GND.
    * TinyPICO: Solder it to the lead of the 22 KOhm resistor.
    * TinyS3: Solder it to the GND pin between 5V and VBAT.
12. Solder the positive (red) wire of the battery to BAT/VBAT.
13. Carefully glue the switch to the enclosure with hot glue (or superglue). Make sure you only glue the tabs or sides of the switch, so it can still slide freely afterwards.
14. Push the two LEDs into the holes close to the switch. LED 1 should go into the left hole (see image for orientation and the table at point 9 to identify which LED is which) and LED 2 in the right hole. Apply some glue if the fit is loose.
15. Solder the black wire connected to GND on the TinyPICO/TinyS3 and the two resistors that are connected to the LEDs to the center lug of the switch. Trim the excess leads of the resistors.
16. If the ground (black) wire of the battery is shorter than 60mm, extend it using the remaining wire of the DFRobot SEN0158. Make sure you cover the solder connection with electrical tape or heat shrink.
17. Solder the ground (black) wire of the battery to the left lug of the switch (see the image for orientation).
18. Slide the DFRobot SEN0158 inside its cavity (from the inside) until it sticks out slightly at the front of the enclosure and loosely clamp it down with the 'SensorBracket'. It should still be able to rotate.<br>
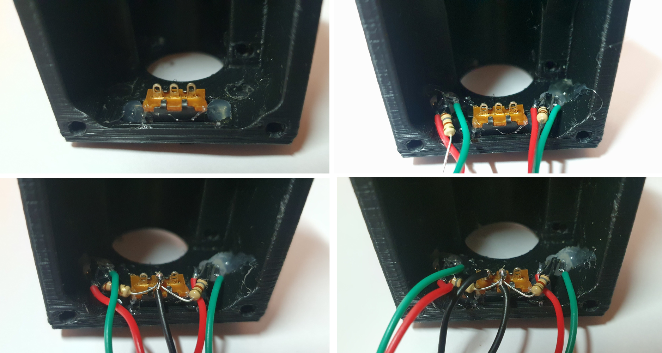
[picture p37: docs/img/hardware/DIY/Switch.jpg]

19. Place the TinyPICO/TinyS3 in it's recess in the enclosure and clamp it down with the 'ControllerBracket' (don't overtighten!).

20. [Update the firmware and webserver onto the sensor.](../Updating/sensorUpdating.md)
21. [Connect the sensor to WiFi.](../SensorConfiguration/sensorConnecting.md)
22. [Go to the 'Coordinates' section of the sensor settings](../SensorConfiguration/sensorSettings.md)
23. Place the sensor down on a flat surface and move a base horizontally in front of it. Now rotate the DFRobot SEN0158 inside the sensor until the movement of the dot in the 'Coordinates' section also moves horizontal.
24. Screw down the DFRobot SEN0158 properly so it cannot move anymore.
25. Insert the battery and screw down the sensor lid and use the M5 bolt and nut to attach the 'MicstandMount' to it.

The sensor is now ready to be used.

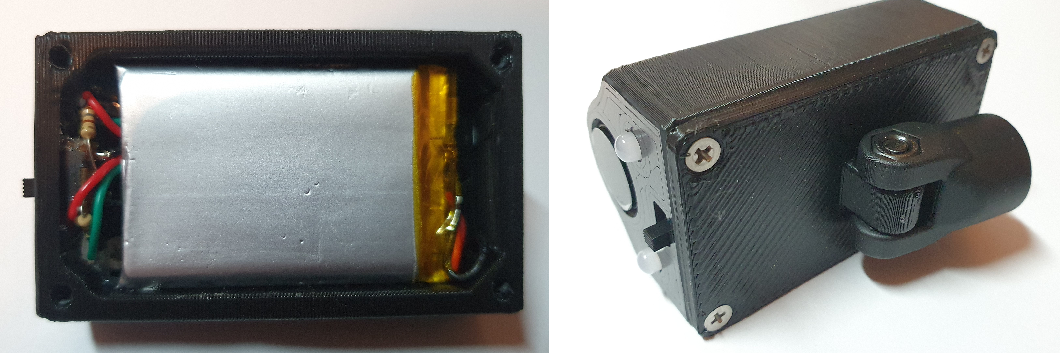
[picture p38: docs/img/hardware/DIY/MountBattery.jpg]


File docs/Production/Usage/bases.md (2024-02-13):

## Switching a Base On or Off
You can switch bases on using the slide switch at the top. Sliding it to the right (towards the LED) switches it on, indicated by 4 flashes of the red LED. Sliding it to the left (away from the LED) switches it off, indicated by 2 flashes of the red LED.

## Base Activation
A base is activated by touching the right of left side of the base, which will switch on the red LED and it will start emitting data to the sensor. You can adjust the sensitivity using Material Companion, as is explained [here](../basePenConfig.md).<br>
If you notice that the base stays activated, try lowering the sensitivity.

## Base Modes
The base has 2 different modes:

* <b>Normal Mode:</b> The base will act as 'normal', where it is in standby until the base is activated by touching it
* <b>Always On Mode:</b> In this mode the base will always emit infrared light. This can be useful for aligning the sensor and performing the sensor calibration procedure

With the sensor on, you can switch between these 2 modes by touching the right side of the base very shortly, waiting for the red LED to switch off, and touching the side of the base again. Repeat this 5 times and the red LED will start blinking rapidly to indicate that it has switched modes.

## Mounting Minis
A mini is placed on top of the bases in order to track the movement of said mini. While it is possible to just place them on there, and let gravity to its work, there are several options for a more secure mounting. Additionally, some guidelines should be followed regarding positioning of the mini on top the base.

### Mini Placement



When mounting a mini on a base, there is one important thing to remember: there needs to be line-of-sight between the infrared LED and the sensor. There are multiple ways in which the placement of the mini can affect this.

The image on the right shows 3 minis, with incorrect placement at the top and correct placement at the bottom.<br>
From left to right:

* The weapon of the mini is directly above the infrared LED. This means that in most situations the sensor will have a hard time detecting the base. This can be solved by rotating the mini.
* The base of the mini blocks the infrared LED, so the sensor cannot detect it. This can be solved by moving the mini a bit.
* The mini is too big for the base. There is no good way to mount it while keeping the infrared LED visible to the sensor. A [base adapter](https://www.materialfoundry.nl/products/base-adapter) can be used for bigger minis.

### Mounting Methods

<b>Magnet on Mini</b><br>
Since the base has an embedded 10x10x1mm magnet, you could use a magnet on the bottom of the mini to keep it mounted securely, while making it easy to remove the mini. You can use either a square ([10x10x1mm](https://www.materialfoundry.nl/products/square-magnet) or similar) or a circular magnet ([10mmx1](https://www.materialfoundry.nl/products/round-magnet) or similar). The advantage of a square magnet is that you can be sure that the mini is correctly aligned, since rotation of the mini on the base is hindered (it can still rotate, but only onto 4 directions). Circular magnets allow more rotational freedom, but this can cause the mini or base to unintentionally rotate.

You will need to take the polarity of the magnet into account. For best results:

1. Place the magnet on top of the base
2. Apply a droplet of superglue to the top of the magnet
3. Place the mini on top of the magnet, holding it in place until dry

To ensure you won't glue the magnet to the base, you could add, for example, plastic film between the base and the magnet.

The attaction between the two magnets might be quite strong. If you are not careful you could break the mini when you try to mount it. For example, if the mini has thin legs, and you hold the mini by its torso while moving it towards the base, the base might fly up to the mini once it's near enough with enough force to break the legs.<br>
It is advisable to take both the base and the mini in hand, and then moving them towards each other, or holding the mini by its base while moving it towards the Material Plane base.

<b>Ferromagnetic Piece of Metal on Mini</b><br>
Instead of magnets (see above), you could use a ferromagnetic piece of metal, since that would also be attracted to the magnet in the base.<br>
The mounting would be less secure, and you won't be able to prevent rotation like a square magnet would, but it should work fine.<br>
Some coins could work for this, for example a 5 eurocent coin.

<b>Double Sided Tape</b><br>
Double sided tape could be used to mount the mini. Depending on how strong the tape is, this is either permanent or semi-permanent. Using weaker tape will allow you to easily switch minis without having to glue anything to the mini, at a risk that the base detaches and falls.<br>
It is possible to make strong tape weaker by touching it repeatedly with your finger.

<b>Glueing the Mini to the Base</b><br>
While not advisable, you could glue the mini directly to the base. Keep in mind that this will prevent you from using [dock expanions](../HardwareOverview/dock.md#base-charging-dock-expansion). You also won't be able to rotate the mini on top of the base, but it will prove the most secure bond.

## Orientation and Holding of Bases

During the [calibration procedure](../calibration.md) you had to keep the orientation of the base constant relative to the display, for example by keeping the LED in the top-right. When using the base during gaming you have to stick to this orientation, so rotating the base is not possible. You can, of course, rotate the mini on top of the base.



When moving bases, you should try to keep them as horizontal as possible. If the base is held at an angle, the relative light emission of the base (so from the perspective of the sensor) is reduced, and if the angle is too big, the sensor will not be able to detect the base.<br>
An exception to this is if the base is located near the edge of the display. In this case, it can be helpful to angle the base towards the sensor.

Make sure your finger or any other object does not obscure the LED to prevent line of sight between the LED and sensor. Because the base is activated by touching one of its sides, this will usually not be an issue.

Take a look at the image on the right, which demonstrates these 2 problems, with the upper images showing the incorect way and the lower images the correct way of holding bases.<br>
From left to right:

* Base held at too much of an angle. Reduce the angle to make it easier for the sensor to detect the base.
* Index finger too close to the infrared LED, which might block the line-of-sight between the LED and sensor. Hold the base with the thumb and index finger, or move the index finger away.

## Token Detection
There are 2 ways Material Plane can detect which token has to be moved when a base is moved:

The main method is to use the id of the base, which can be linked to a specific token or actor. This means that whenever a specific base is moved, it will only move the linked token or actor (see [Base Setup](../Foundry/foundryConfig.md#base-setup) for more info on how to configure that).

A secondary, fallback method is to use the location of the base. Whenever a base is moved, Material Plane checks if there are any tokens close enough. If there are, it will pick the nearest (that is allowed to be moved) and move that token. The disadvantage of this method is that if any interruption occurs, the token might be dropped. It can also result in the wrong token being moved if multiple tokens are close to each other.

Whenever more than one base is moved at a time, or the pen is used at the same time, the fallback method is always used.

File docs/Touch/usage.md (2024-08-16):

Mini movement is determined by the selected [touch mode](./Foundry/foundryConfig.md#touch-modes).

* <b>Direct:</b> Touch and drag a token to move it. 
* <b>Tap Timeout:</b> Touch a token for a short amount of time (configured by the ['Tap Timeout'](./Foundry/foundryConfig.md#touch) setting), after which a token can be moved. For infrared touch frames it is required to raise the mini before movement.
* <b>Raise Mini:</b> To move a mini, you must first raise the mini from the screen, then after lowering it again on the screen, you can move it around.
This raise mini procedure is implemented to counter some of the issues related to touch frames: In certain situations, movement of a mini can influence the detected location of another mini. Since that other mini is probably not activated when this issue occurs, it should no longer be influenced by the movement of the first mini.

The token that is nearest to the touch will be activated (within approximately 1 grid space). So if there are 2 tokens next to each other, you have to make sure that you touch the correct token.

Once a token has been activated, it will be selected and follow the touch. The exact movement and vision behavior is determined by the ['Movement Method'](./Foundry/foundryConfig.md#control). The token will be dropped once no movement is detected for a certain period of time (determined by ['Token Drop Timeout'](./Foundry/foundryConfig.md#touch)), so to ensure that a token isn't accidentally dropped, you might want to keep moving it.

If the token is at its desired location, you release the touch, and it will be dropped after some time (determined by ['Token Drop Timeout'](./Foundry/foundryConfig.md#touch)). If ['Deselect Token After Drop'](./Foundry/foundryConfig.md#control) is enabled the token will be deselected, which will cause Foundry to display the vision of all owned tokens, otherwise the token will stay selected until deselected through some other means.

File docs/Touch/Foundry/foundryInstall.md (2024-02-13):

{% include 'foundryConfig-install.md' %}

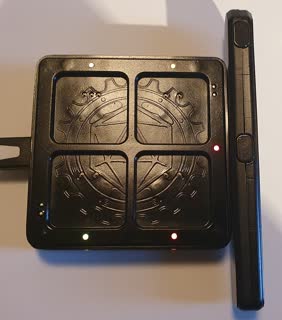
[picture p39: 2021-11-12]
Img/Beta Hardware/Guide/.thumb/Pen_Charging.jpg.jpg

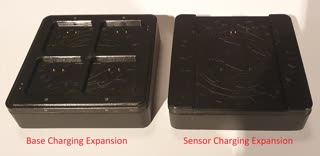
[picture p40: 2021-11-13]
Img/Beta Hardware/Guide/.thumb/Dock_Expansions.jpg.jpg

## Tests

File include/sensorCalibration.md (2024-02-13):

To function properly, the sensor needs to know the position of your display. To do this, a calibration procedure is required where you tell the sensor where the 4 corners of your display are.<br>
<br>

Calibration is performed in the [Sensor](Foundry/foundryConfig.md#sensor) tab of the 'Material Plane Configuration' screen.<br>
Under the 'Calibration' section you can find 2 checkboxes. These checkboxes allow you to enable or disable the calibration and calibration offset. Switching them off will result in the sensor outputting raw position data, switching them on will result in the sensor outputting calibrated data (assuming you've performed the calibration procedure).<br>
<br>
Below that there's a 'Calibrate' button that will start the calibration procedure.

You should make sure the sensor is correctly [configured](SensorConfiguration/sensorSettings.md) before calibrating.

There are 3 calibration options:

* <b>[Single-Point Calibration](#single-point-calibration):</b> Each calibration point is measured one at a time
* <b>[Multipoint Calibration](#multipoint-calibration):</b> All 4 calibration points are measured at the same time
* <b>[Offset Calibration](#offset-calibration):</b> This allows you to configure offsets from the normal calibration points, allowing you to define your own (more convenient) calibration points

<b>Note</b>: Calibration must be performed using bases, you cannot calibrate with a pen. 

## Base Positioning During Calibration


When calibrating the sensor, there are 2 important things to note regarding base positioning:

### Base Orientation
The orientation of the base, relative to the display, must stay constant during calibration (and normal use). For example, take the image on the right, which shows a TV inside a wooden enclosure. The base is rotated so the LED on the base is located on the top-right side. For each calibration point, the base rotation must stay the same, so for each calibration point the LED has to be located on the top-right side.

### Base Location
Unless you use offset calibration, you will need to align the center of the base with the corner of the (active part of the) display. Take a look at the 2 bottom images on the right. In the right (incorrect) image, a base is located inside the (raised) bezel of the display while another is located on the outside corner of the whole display (the corner of the bezel). In the left image the base is correctly located, with the center of the base aligned with the corner of the display.

## Single-Point Calibration
Using single-point calibration you calibrate each corner one at a time.



1. Make sure Foundry is running full-screen (F11).
2. Select 'Single-Point Calibration'.
3. After pressing the 'Calibrate' button, a popup window will appear with a table for the 4 corners of your display.
4. Activate a base by {{ baseActivation }} and move it to one of the corners of your display, the coordinates should show up in grey for point 0. <b>Make sure the center of the base aligns with the corner of your display, see [here](#base-positioning-during-calibration).</b>
5. Release the base and wait a few seconds or press the 'Next' button to move to the next point. The calibration point is now locked in and its coordinates should turn black.
6. Repeat this process for all 4 corners, you can do the corners in any order.
7. After the 4th corner the calibration procedure is completed. Either close the popup manually or wait 5 seconds for the popup to close automatically.
8. Exit the 'Material Plane Configuration' screen and try to move a token. If the procedure went correctly the token will stay directly underneath the base. Move it across the entire display to make sure the calibration is correct everywhere.
9. If the token does not stay directly underneath the base take note of [how accurate the calibration should be](#calibration-accuracy).

## Multipoint Calibration
Using multipoint calibration you calibrate all four corners of your display at the same time. To do this you must use 4 bases or other infrared sources and have them activated at the same time. This can be done {% if variant == 'production' %} using the production bases, or by {% endif %} mounting 4 infrared LEDs close to the display and using [offset calibration](#offset-calibration).

{% if variant == 'production' %}
The easiest way to do this is to put the bases in 'always-on' mode: Touch the side of the base very short, wait for the red LED to switch off, touch the side of the base again. Repeat this 5 times and the red LED will start blinking.
{% endif %}



1. Make sure Foundry is running full-screen (F11).
2. Select 'Multipoint Calibration'.
3. After pressing the 'Calibrate' button, a popup window will appear with a table for the 4 corners of your display.
4. Switch on the infrared LEDs {% if variant == 'production' %}or move 4 bases into each corner of your display, <b>making sure the center of the bases aligns with the corners of your display, see [here](#base-positioning-during-calibration)</b>{% endif %}. The coordinates of the should show up in the table.
5. When you're happy, press 'Calibrate', and the calibration procedure is done.
7. Exit the 'Material Plane Configuration' screen and try to move a token. If the procedure went correctly the token will stay directly underneath the base. Move it across the entire display to make sure the calibration is correct everywhere.
8. If the token does not stay directly underneath the base take note of [how accurate the calibration should be](#calibration-accuracy).

## Offset Calibration


With the previous calibration methods you had to align the center of the base exactly with the corners of your display. Using offset calibration you can choose different points to calibrate to.<br>
What offset calibration essentially does is defining the offset of the calibration points from the corner of the display. As long as the position of these offset calibration points don't move with respect to the display, they should always give the same calibration results.

For example, as shown in the image on the right, your display has a raised bezel. Using offset calibration you can move the base into the corner created by the bezel and use that as the calibration point. This allows for a fast and easy to locate calibration point.

Another option, also shown in the image, is to embed 4 infrared LEDs into the display enclosure or gaming table. In this case, all you would need to do to calibrate is starting the multipoint calibration and switching on the LEDs.

1. Calibrate using 'Single-Point' or 'Multipoint' calibration, but instead of placing bases in the corners of your display, you use your self-defined calibration points (for example the base inside the raised bezel or the embedded infrared LEDs).
2. Select 'Offset' calibration, and follow the exact procedure for 'Single-Point' calibration. This time you do need to place the bases on the corners of your display. <b>Make sure the center of the base aligns with the corner of your display, see [here](#base-positioning-during-calibration).</b>

Once you have performed these steps, whenever you need to recalibrate you only need to perform step 1 using your self-defined calibration points.

## Calibration Accuracy
Getting a perfect calibration can be difficult, because aliging the center of the base with the corner of the display can, depending on the geometry of your display, be difficult. There might also be other (scaling) issues. {% if variant == 'production' %}
If the sensor has the lens installed a slight fisheye distortion is also to be expected.
{% endif %}

During normal use some inaccuracy isn't a problem, because tokens will snap to the grid. This means that the inaccuracy should be small enough that if a base is located exactly on the grid, the token is at least 50% inside the intended grid space.

An inaccuracy smaller than 1/3 of a grid space in either x or y direction can probably be ignored. To make sure no problems arise, move a token across the entire display to check that the inaccuracy falls below that everywhere.

If you notice that the inaccuracy is constant across the entire display, you could introduce an x or y offset in the [transform](SensorConfiguration/sensorSettings.md#transform) section of the sensor settings. If the inaccuracy does not stay constant, you could try changing the x or y scale, also in the [transform](SensorConfiguration/sensorSettings.md#transform) section of the sensor settings.

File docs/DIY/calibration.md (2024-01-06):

{% set baseActivation = 'pressing the switch on the base' %}

# Sensor Calibration
{% include 'sensorCalibration.md' %}

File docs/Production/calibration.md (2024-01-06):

{% set variant = 'production' %}

{% set baseActivation = 'touching one of the sides of the base' %}

# Sensor Calibration
{% include 'sensorCalibration.md' %}

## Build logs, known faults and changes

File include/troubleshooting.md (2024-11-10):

## How to use
Below you will find multiple tables covering different topics related to Material Plane.<br>
For easy navigation, each table can be found in the table of contents on the left.<br>
Pick the table that best corresponds with your issue, if you cannot find your issue there, make sure it's not located somewhere else.<br>
If your issue is nowhere to be found, or you found a solution that isn't mentioned here, please contact me.

Issues can have multiple causes or multiple solutions.<br>
If you find a row that does not mention an issue, it relates to the issue in the row above it.<br>
Similarly, if you find a row that does not mention a possible cause, it relates to the issue and possible cause of the row above it.

## Sensor
| Issue | Possible cause | Possible solution | More info |
|---|---|---|---|
| Sensor can't detect base/pen | Sensor sensitivity set incorrectly | Properly configure the sensor | [link](SensorConfiguration/sensorSettings.md#exposure) |
| Sensor can't detect base/pen at edge of display | Sensor sensitivity set incorrectly | Properly configure the sensor | [link](SensorConfiguration/sensorSettings.md#exposure) |
| | Sensor too close to the display | Properly configure the sensor | [link](SensorConfiguration/sensorSettings.md#exposure) | 
| Sensor detects a lot of noise | Minimum brightness set too low | Increase minimum brightness | [link](SensorConfiguration/sensorSettings.md#exposure)
| | Too much infrared noise in room | Switch all infrared sources off, such as: <br>-Wii sensor bar<br>-VR stations/receivers
| | | Prevent direct sunlight on the sensor/display/table
| | | Make sure there are no lights shining/reflecting directly into the sensor
| Sensor can't detect complete display | Sensor too close to the display | Move sensor further back | [link](SensorPositioning/sensorDistance.md) |
{% if variant == 'production' %}|                   |                                       | Install a wide-angle lens                 | [link](SensorConfiguration/sensorLens.md)                 |
{% endif %}| Sensor won't charge                    | Sensor is not getting (enough) power  | Connect USB cable to power adapter        |
|                                                   |                                       | Try a different power adapter             |
|                                                   | Broken cable                          | Replace cable                             |
| Sensor can't connect to WiFi                      | Wrong credentials                     | Enter correct credentials                 |
|                                                   | No 2.4GHz WiFi available              | Make sure there's 2.4GHz WiFi available   |
|                                                   | Router too far away                   | Move router or sensor closer, or get a WiFi extender    |
| Detected points move in wrong direction           | Mirroring and/or rotation not configured properly | Properly configure mirroring and/or rotation  | [link](SensorConfiguration/sensorSettings.md#transform)
{% if variant == 'production' %}| Incorrect battery readings  | Battery has been replaced             | Reset battery configuration                           | [link](SensorConfiguration/webserver.md#status-tab)   
|                                                   | Bug                                   | Reset battery configuration                           | [link](SensorConfiguration/webserver.md#status-tab)   
{% elif variant == 'diy' %}| Incorrect battery readings    | Battery reading is only a very rough estimate | No solution
| No battery readings during charging               | This is on purpose: During charging, the battery voltage is read much too high, making the voltage reading useless | No solution{% endif %}

{% if variant == 'production' %}
## Base
| Issue | Possible cause | Possible solution | More info |
|---|---|---|---|
| Base won't update | Both the pen and base are connected to the dock | Remove one of them | [link](Updating/basePenUpdating.md) |
| | Faulty USB-C cable or USB port | Try a different cable or USB port
| | Incorrect or no USB drivers installed | Install the drivers | [link](https://learn.sparkfun.com/tutorials/how-to-install-ch340-drivers/all#drivers-if-you-need-them) |
| Base won't charge | Dock is not getting power | Apply power to the dock | 
| | Dock is getting insufficient power | Try a different power adapter that can supply enough power | [link](HardwareOverview/dock.md#power-supply-requirements) |
| | Too many dock expansions stacked | Try removing dock expansions | [link](HardwareOverview/dock.md#expansion-stacking-limitations)  |
| | Base not seated correctly | Try reseating it | [link](HardwareOverview/dock.md#base-charging)  |
| Base won't detect touch | Base switched off | Switch base on | [link](Usage/bases.md#switching-a-base-on-or-off)
| | Touch sensitivity set too low | Increase touch sensitivity | [link](basePenConfig.md#configuration-options)
| | Wrong (pen?) firmware installed | Install the correct firmware | [link](Updating/basePenUpdating.md)
| Base won't go into standby (LED always on) | Base is in 'Always On Mode' | Switch base back to 'Normal' mode | [link](Usage/bases.md#base-modes)
| | Touch sensitivity set too high | Decrease touch sensitivity | [link](basePenConfig.md#configuration-options)
| Base becomes active when placed on display | Touch sensitivity set too high | Decrease touch sensitivity | [link](basePenConfig.md#configuration-options)

## Pen
| Issue | Possible cause | Possible solution | More info |
|---|---|---|---|
| Pen won't update | Both the pen and base are connected to the dock | Remove one of them | [link](Updating/basePenUpdating.md) |
| | Faulty USB-C cable or USB port | Try a different cable or USB port |
| | Incorrect or no USB drivers installed | Install the drivers | [link](https://learn.sparkfun.com/tutorials/how-to-install-ch340-drivers/all#drivers-if-you-need-them) |
| Pen/ won't charge | Dock is not getting power | Apply power to the dock | 
| | Dock is getting insufficient power | Try a different power adapter that can supply enough power | [link](HardwareOverview/dock.md#power-supply-requirements) |
| | Too many dock expansions stacked | Try removing dock expansions | [link](HardwareOverview/dock.md#expansion-stacking-limitations)  |
| | Pen not seated correctly | Try reseating it | [link](HardwareOverview/dock.md#base-charging)  |
{% endif %}

## Calibration
| Issue | Possible cause | Possible solution | More info |
|---|---|---|---|
| Can't perform/complete calibration | Active user not configured correctly | Configure active user | [link](Foundry/foundryConfig.md#general)
| | Active user not connected to Foundry | Connect active user
| | Sensor not connected | See [above](#sensor)
| | Sensor sensitivity not set correctly | Configure sensor | [link](SensorConfiguration/sensorSettings.md#exposure)
| | Base not enabled | Switch on base
| | Sensor can't see entire display | See [above](#sensor)
| Tokens don't stay directly below base | No calibration performed | Perform calibration | [link](calibration.md)
| | Calibration disabled | Enable calibration | [link](calibration.md)
| | Calibration not done correctly | Perform calibration, make sure you check [Base Orientation](calibration.md#base-orientation) | [link](calibration.md)
| | Sensor offset and/or scaling set incorrectly | Correctly configure offset and/or scaling | [link](SensorConfiguration/sensorSettings.md#transform)
| Detected points move in wrong direction | Mirroring and/or rotation not configured properly | Properly configure mirroring and/or rotation  | [link](SensorConfiguration/sensorSettings.md#transform)

## Foundry VTT
| Issue | Possible cause | Possible solution | More info |
|---|---|---|---|
| Can't see module in Foundry's module page | No internet connection | Make sure you are connected to the internet |
| | Foundry server down | Wait until the server is up again |
| | Incompatible Foundry version | Upgrade/downgrade to a compatible version |
| | Bug in the module | Report it to me |
| | Bug in Foundry | Report it to the Foundry team |
| Can't install module | Bug in the module | Report it to me |
| | Bug in Foundry | Report it to the Foundry team |
| Can't update module | No internet connection | Make sure you are connected to the internet |
| | Incompatible Foundry version | Upgrade/downgrade to a compatible version |
| | Bug in the module | Report it to me |
| | Bug in Foundry | Report it to the Foundry team |
| Sensor won't connect to module | Sensor not connected to WiFi | Connect sensor to WiFi | [link](SensorConfiguration/sensorConnecting.md)
| | Incorrect 'Connection Mode' selected | Select correct mode | [link](Foundry/foundryConnection.md)
| | Incorrect 'Sensor Module IP Address' configured | Configure correct address | [link](Foundry/foundryConnection.md)
| | Foundry server is secured | Connect through Material Companion | [link](Foundry/foundryConnection.md)
| Tokens don't move | Sensor is not connected to WiFi | Connect sensor to WiFi | [link](SensorConfiguration/sensorConnecting.md)
| | Sensor is not connected to module | Connect sensor to module | [link](Foundry/foundryConnection.md)
| | Sensor is not correctly calibrated | Perform calibration | [link](calibration.md)
| | Sensor mirroring/rotation not configured correctly| Configure mirroring and/or rotation | [link](SensorConfiguration/sensorSettings.md#transform) 
| | Sensor sensitivity is not set correctly | Configure sensor | [link](SensorConfiguration/sensorSettings.md) 
| | Token is not owned by display user | Make display user owner of token | [link](Foundry/foundrySetup.md) 
| | | Enable 'Non-Owned Movement' | [link](Foundry/foundryConfig.md) 
| Wrong tokens are being moved | Sensor not correctly calibrated | Perform calibration | [link](calibration.md)
| | Sensor mirroring/rotation not configured correctly| Configure mirroring and/or rotation | [link](SensorConfiguration/sensorSettings.md#transform) 
| Tokens don't stay directly below base | Sensor not configured properly | Configure sensor | [link](SensorConfiguration/sensorSettings.md) 
| Tokens are not dropped after releasing base | Module is configured to not drop tokens | Enable 'Delect Token After Drop' | [link](Foundry/foundryConfig.md#general)
| Tokens can move through walls | This is a known issue that has been hard to solve | Try to avoid having walls through the middle of a grid space  |
| Detected points move in wrong direction | Mirroring and/or rotation not configured properly | Properly configure mirroring and/or rotation | [link](SensorConfiguration/sensorSettings.md#transform)

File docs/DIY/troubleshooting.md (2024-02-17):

{% set variant = 'diy' %}

{% include 'troubleshooting.md' %}

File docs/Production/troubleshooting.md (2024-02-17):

{% set variant = 'production' %}

{% include 'troubleshooting.md' %}

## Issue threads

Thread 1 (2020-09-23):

Big minis ( >1 gridspace) don't center correctly, need compensation

CDeenen, 2020-09-23:
IR LED is always at the top left of the mini, this gives problems when a mini is big, because the center of that mini is furter away from the LED than the center of a small mini.
Should be easy to fix by looking at the in-game size of the token

Closed 2020-09-27.

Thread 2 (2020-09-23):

There's sometimes an offset between the IR LED coordinates and the measured location

CDeenen, 2020-09-23:
Probably a mistake in calculating the coordinates, that's amplified on bigger screens.

CDeenen, 2020-09-27:
Added a workaround using X and Y compensation in calibration menu. Will need to investigate this further.

Closed 2021-07-15.

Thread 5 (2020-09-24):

Contact info?

Arlllen, 2020-09-24:
Hi man!
Really love your idea, and that's a blessing to have such a module and technology . But I can't find any info on how to contact you.
I'm not tech savvy guy, but I really want that thing to be a part of my table.
If that's possible I would like to buy the product or the parts to assemble it without cutting wires or anything like that
Perhaps 1 camera and 6 bases for minis

My contacts:
Discord: Аклеон#3277

CDeenen, 2020-09-24:
Hey, thank you for your interest.

My email and discord are at the bottom of the main readme, they're: cdeenen@outlook.com and Cris#6864

I removed your telegram and phone number from the above post, because you might not want them here for all to see.

Currently I do not sell any of the parts, I want to make sure everything works and I have finalized the hardware.
Considering the interest this module has gotten, I'm pretty sure I'll start selling kits soon.

Closing this issue, if you have further questions you now know where to find me :)

Closed 2020-09-24.

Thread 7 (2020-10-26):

Add SSL support

CDeenen, 2020-10-26:
SSL is not supported because the Arduino websocket library currently doesn't support SSL servers.
Workaround could be possible using a proxy, will be investigated

CDeenen, 2020-12-03:
Material Server could be used as a proxy

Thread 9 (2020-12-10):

Possible New Idea (Suggestion)

Sonny-Crockett, 2020-12-10:
I have used Go(Baduk) tracking software for many years, following different variations of it. Now its a simpler problem because its just black and white stones, but I think with the advances in technology regard image recognition, something like this could be expanded on for RPG with Video Table Tops.

Just thinking in basic terms, the Foundry VTT program could have "anchor" images on the corners that would help tell the Webcam where the Grid is. My hope for this as an option would mean easier adoption but I understand it would require more coding. I just wanted to share this idea from my experience.

http://www.oipaz.net/2016-KSFBS.pdf - Scientific Paper on VideoKifu

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

CDeenen, 2020-12-10:
Thank you for your suggestion.
The camera used for Material Plane can only detect IR, so the only way to permanently anchor the grid would be to have 4 corner IR LEDs on all the time. This isn't really possible because it'll cause issues when trying to track minis.
What you can do, is only turn on the corner LEDs during a calibration procedure, and as long as the LEDs are always in the same location relative to the grid, you can very quickly calibrate the sensor. You can already do that with Material Plane, using the Multipoint Calibration option.
Thanks for the paper, I'll read through it when I have some more time. There might be stuff in there that's useful for Material Plane.

Closed 2021-07-15.

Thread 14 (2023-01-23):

Add buttons in corner for moving/ zooming map an tv

Kallimeister, 2023-01-23:
Option to add a corner with controls to move and zoom the map so it can be adjusted to the situation without the use of a mouse

CDeenen, 2023-01-23:
I can look at adding something like that.
You could also have a look at Lock View, which allows the DM to control the view on the TV.

Kallimeister, 2023-01-25:
Lock View is exactly what i needed. Didn't know you alredy did that one. Thank you so much!

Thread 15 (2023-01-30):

Cant compile Hardware with esp32 2.0.6

P4rziv4l99, 2023-01-30:
Hi, I am trying to compile the software for the diy hardware for an TinyS3 board because of shortage of TinyPicos.
if i am trying to compile with the esp32 module v2.0.6 i get an error for every board:

```
Arduino: 1.8.19 (Windows 10), Board: "UM TinyS3, Core 1, Core 1, USB-OTG (TinyUSB), Enabled, Disabled, Disabled, USB-OTG CDC (TinyUSB), Enabled, Default (3MB APP/1.5MB SPIFFS), 240MHz (WiFi), QIO, 921600, None, Disabled"

In file included from C:\Users\Nhamp\Downloads\MaterialPlane_Hardware-master\MaterialPlane_Hardware-master\Sensor\src\IR32\src\IRRecv.cpp:1:

C:\Users\Nhamp\Downloads\MaterialPlane_Hardware-master\MaterialPlane_Hardware-master\Sensor\src\IR32\src\IRRecv.h:36:10: error: 'vector' in namespace 'std' does not name a template type

     std::vector<uint8_t> _preferred;

          ^~~~~~

C:\Users\Nhamp\Downloads\MaterialPlane_Hardware-master\MaterialPlane_Hardware-master\Sensor\src\IR32\src\IRRecv.h:36:5: note: 'std::vector' is defined in header '<vector>'; did you forget to '#include <vector>'?

C:\Users\Nhamp\Downloads\MaterialPlane_Hardware-master\MaterialPlane_Hardware-master\Sensor\src\IR32\src\IRRecv.h:7:1:

+#include <vector>

C:\Users\Nhamp\Downloads\MaterialPlane_Hardware-master\MaterialPlane_Hardware-master\Sensor\src\IR32\src\IRRecv.h:36:5:

     std::vector<uint8_t> _preferred;

     ^~~

C:\Users\Nhamp\Downloads\MaterialPlane_Hardware-master\MaterialPlane_Hardware-master\Sensor\src\IR32\src\IRRecv.cpp: In member function 'int8_t IRRecv::available()':

C:\Users\Nhamp\Downloads\MaterialPlane_Hardware-master\MaterialPlane_Hardware-master\Sensor\src\IR32\src\IRRecv.cpp:49:54: error: too few arguments to function 'void vRingbufferGetInfo(RingbufHandle_t, UBaseType_t*, UBaseType_t*, UBaseType_t*, UBaseType_t*, UBaseType_t*)'

    vRingbufferGetInfo(_rb, NULL, NULL, NULL, &waiting);

                                                      ^

In file included from C:\Users\Nhamp\AppData\Local\Arduino15\packages\esp32\hardware\esp32\2.0.6/tools/sdk/esp32s3/include/driver/include/driver/rmt.h:19,

                 from C:\Users\Nhamp\Downloads\MaterialPlane_Hardware-master\MaterialPlane_Hardware-master\Sensor\src\IR32\src\IRRecv.h:6,

                 from C:\Users\Nhamp\Downloads\MaterialPlane_Hardware-master\MaterialPlane_Hardware-master\Sensor\src\IR32\src\IRRecv.cpp:1:

C:\Users\Nhamp\AppData\Local\Arduino15\packages\esp32\hardware\esp32\2.0.6/tools/sdk/esp32s3/include/esp_ringbuf/include/freertos/ringbuf.h:500:6: note: declared here

 void vRingbufferGetInfo(RingbufHandle_t xRingbuffer,

      ^~~~~~~~~~~~~~~~~~

C:\Users\Nhamp\Downloads\MaterialPlane_Hardware-master\MaterialPlane_Hardware-master\Sensor\src\IR32\src\IRRecv.cpp: In member function 'uint32_t IRRecv::read(char*&, bool)':

C:\Users\Nhamp\Downloads\MaterialPlane_Hardware-master\MaterialPlane_Hardware-master\Sensor\src\IR32\src\IRRecv.cpp:142:27: error: '_preferred' was not declared in this scope

     for (uint8_t timing : _preferred) {

                           ^~~~~~~~~~

C:\Users\Nhamp\Downloads\MaterialPlane_Hardware-master\MaterialPlane_Hardware-master\Sensor\src\IR32\src\IRRecv.cpp:142:27: note: suggested alternative: 'setPreferred'

     for (uint8_t timing : _preferred) {

                           ^~~~~~~~~~

                           setPreferred

C:\Users\Nhamp\Downloads\MaterialPlane_Hardware-master\MaterialPlane_Hardware-master\Sensor\src\IR32\src\IRRecv.cpp: In member function 'bool IRRecv::inPrefVector(uint8_t)':

C:\Users\Nhamp\Downloads\MaterialPlane_Hardware-master\MaterialPlane_Hardware-master\Sensor\src\IR32\src\IRRecv.cpp:182:18: error: '_preferred' was not declared in this scope

     for (int x : _preferred) if (x == element) return true;

                  ^~~~~~~~~~

C:\Users\Nhamp\Downloads\MaterialPlane_Hardware-master\MaterialPlane_Hardware-master\Sensor\src\IR32\src\IRRecv.cpp:182:18: note: suggested alternative: 'setPreferred'

     for (int x : _preferred) if (x == element) return true;

                  ^~~~~~~~~~

                  setPreferred

C:\Users\Nhamp\Downloads\MaterialPlane_Hardware-master\MaterialPlane_Hardware-master\Sensor\src\IR32\src\IRRecv.cpp: In member function 'int IRRecv::setPreferred(const char*)':

C:\Users\Nhamp\Downloads\MaterialPlane_Hardware-master\MaterialPlane_Hardware-master\Sensor\src\IR32\src\IRRecv.cpp:189:9: error: '_preferred' was not declared in this scope

         _preferred.clear();

         ^~~~~~~~~~

C:\Users\Nhamp\Downloads\MaterialPlane_Hardware-master\MaterialPlane_Hardware-master\Sensor\src\IR32\src\IRRecv.cpp:189:9: note: suggested alternative: 'setPreferred'

         _preferred.clear();

         ^~~~~~~~~~

         setPreferred

C:\Users\Nhamp\Downloads\MaterialPlane_Hardware-master\MaterialPlane_Hardware-master\Sensor\src\IR32\src\IRRecv.cpp:196:38: error: '_preferred' was not declared in this scope

         if (!inPrefVector(position)) _preferred.push_back(position);

                                      ^~~~~~~~~~

C:\Users\Nhamp\Downloads\MaterialPlane_Hardware-master\MaterialPlane_Hardware-master\Sensor\src\IR32\src\IRRecv.cpp:196:38: note: suggested alternative: 'setPreferred'

         if (!inPrefVector(position)) _preferred.push_back(position);

                                      ^~~~~~~~~~

                                      setPreferred

C:\Users\Nhamp\Downloads\MaterialPlane_Hardware-master\MaterialPlane_Hardware-master\Sensor\src\IR32\src\IRRecv.cpp:197:16: error: '_preferred' was not declared in this scope

         return _preferred.size();

                ^~~~~~~~~~

C:\Users\Nhamp\Downloads\MaterialPlane_Hardware-master\MaterialPlane_Hardware-master\Sensor\src\IR32\src\IRRecv.cpp:197:16: note: suggested alternative: 'setPreferred'

         return _preferred.size();

                ^~~~~~~~~~

                setPreferred

Mehrere Bibliotheken wurden für "WiFi.h" gefunden

 Benutzt: C:\Users\Nhamp\AppData\Local\Arduino15\packages\esp32\hardware\esp32\2.0.6\libraries\WiFi

 Nicht benutzt: C:\Program Files (x86)\Arduino\libraries\WiFi

Mehrere Bibliotheken wurden für "ArduinoOTA.h" gefunden

 Benutzt: C:\Users\Nhamp\AppData\Local\Arduino15\packages\esp32\hardware\esp32\2.0.6\libraries\ArduinoOTA

 Nicht benutzt: D:\OneDrive\Documents\Arduino\libraries\ArduinoOTA

exit status 1

Fehler beim Kompilieren für das Board UM TinyS3.

Dieser Bericht wäre detaillierter, wenn die Option
"Ausführliche Ausgabe während der Kompilierung"
in Datei -> Voreinstellungen aktiviert wäre.
```

CDeenen, 2023-01-30:
The problem is that the TinyS3 uses the ESP32-S3 microcontroller, while the DIY hardware requires a normal ESP32. One of the libraries used isn't compatible with the S3.
However, since the new hardware I'm working on is running on an ESP32-S3, the next version of the firmware should also be compatible with the TinyS3.

What might work in the meantime is to remove `#include "src/IR32/src/IRRecv.h"` from line 28 of Sensor.ino. It is not used by the DIY hardware anyway. It is possible that new problem pop up, though.

P4rziv4l99, 2023-02-01:
hey man, thanks for your quick responde.
i got it to work with an esp32 Devkit and esp 1.0.6. just wanted to thank you for this amazing project and making it open source.

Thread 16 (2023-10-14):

Failing to Upload

bpbarwick, 2023-10-14:
I am attempting to upload to a TinyS3 using an esp32 Dev Kit and esp version 1.0.6 as stated in this [other issue](https://github.com/MaterialFoundry/MaterialPlane/issues/15). Arduino IDE is able to compile, but fails to upload with the following error message. This may very well be something I am doing wrong, but I have followed the Material Foundry instructions step by step on two different computers now with the same results.

```
Arduino: 1.8.19 (Windows 10), Board: "ESP32 Dev Module, Disabled, Default 4MB with spiffs (1.2MB APP/1.5MB SPIFFS), 240MHz (WiFi/BT), QIO, 80MHz, 4MB (32Mb), 921600, None"

Sketch uses 1060246 bytes (80%) of program storage space. Maximum is 1310720 bytes.

Global variables use 51568 bytes (15%) of dynamic memory, leaving 276112 bytes for local variables. Maximum is 327680 bytes.

C:\Users\bpbar\AppData\Local\Arduino15\packages\esp32\tools\esptool_py\3.0.0/esptool.exe --chip esp32 --port COM5 --baud 921600 --before default_reset --after hard_reset write_flash -z --flash_mode dio --flash_freq 80m --flash_size detect 0xe000 C:\Users\bpbar\AppData\Local\Arduino15\packages\esp32\hardware\esp32\1.0.6/tools/partitions/boot_app0.bin 0x1000 C:\Users\bpbar\AppData\Local\Arduino15\packages\esp32\hardware\esp32\1.0.6/tools/sdk/bin/bootloader_qio_80m.bin 0x10000 C:\Users\bpbar\AppData\Local\Temp\arduino_build_888661/Sensor.ino.bin 0x8000 C:\Users\bpbar\AppData\Local\Temp\arduino_build_888661/Sensor.ino.partitions.bin

esptool.py v3.1-dev

Serial port COM5

Connecting...

Traceback (most recent call last):

  File "esptool.py", line 4423, in <module>

  File "esptool.py", line 4416, in _main

  File "esptool.py", line 3966, in main

  File "esptool.py", line 120, in get_default_connected_device

  File "esptool.py", line 567, in connect

  File "esptool.py", line 539, in _connect_attempt

  File "esptool.py", line 478, in sync

  File "esptool.py", line 414, in command

  File "esptool.py", line 377, in write

  File "site-packages\serial\serialwin32.py", line 323, in write

serial.serialutil.SerialTimeoutException: Write timeout

Failed to execute script esptool

An error occurred while uploading the sketch

This report would have more information with
"Show verbose output during compilation"
option enabled in File -> Preferences.
```

CDeenen, 2023-10-14:
Hey, as I mentioned in the other issue, the current DIY firmware does not work on an esp32-s3 (which the TinyS3 is). Simply setting the board to an esp32 devkit won't work, because you don't have an esp32 devkit connected and during the firmware upload the software notices this.
What the other person did was buy an esp32 devkit. You could do the same, or wait until I have made the latest firmware version (currently only for the production sensor) available for the DIY sensor.
If you decide to buy another board, please double check that it is actually an esp32 board, and not some variant (such as the esp32-s2, esp32-s3, esp32-c2, etc). You might have to look at the product details, not just the product name. For example, the Arduino Nano Esp32 is actually an esp32-s3.

bpbarwick, 2023-10-15:
Thanks for the explanation and sorry for my stupidity! I guess I had just scanned over that other issue and missed that key point. I appreciate your timely response.

Closed 2023-10-15.

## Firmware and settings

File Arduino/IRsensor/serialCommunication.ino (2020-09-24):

int checkSerial(){
  data = Serial.readStringUntil('\n');    
  analyzeData(data);
}

int analyzeData(String received) {
  

  String received2[6] = {"","","","","",""};                                            //Stores the read string as individual words
  int counter = 0;                                                                  //Word counter
  for (int i=0; i<(received.length()-1); i++) {                                         //Check each individual character in the received string
    if (received[i] == ' ')                                                             //If the character is a space, increment the word counter
      counter++;
    else                                                                            //If the character is no space, add the character to the current word
      received2[counter] += received[i];
  }

  Serial.print("Rec1: ");
  Serial.print(received2[0]);
  Serial.print("\tRec2: ");
  Serial.print(received2[1]);
  Serial.print("\tRec3: ");
  Serial.println(received2[2]);

  if (received2[0] == "SENS"){
    setSensitivity(received2[1].toInt());
    storeSensitivity();
    return 1;
  }
  else if (received2[0] == "CAL"){
    if (received2[1] == "SINGLE") {
      getCal();
      storeCalEn();
      storeCal();
      return 1;
    }
    else if (received2[1] == "MULTI") {
      getCalMulti();
      storeCalEn();
      storeCal();
      return 1;
    }
    else if (received2[1] == "EN"){
      if (received2[2] == "1") homography = true;
      else if (received2[2] == "0") homography = false;
      else return 0;
      storeCalEn();
      return 1;
    }
    else if (received2[1] == "GET"){
      printf("CALEN: %d\t",homography);
      for (int i=0; i<4; i++) printf("CALX%d: %d\tCALY%d: %d\t",i,cal[0][i],i,cal[1][i]);
      Serial.println();
    }
    else return 0;
  }
  else if (received2[0] == "OFFSET") {
    if (received2[1] == "EN"){
      if (received2[2] == "1") offsetOn = true;
      else if (received2[2] == "0") offsetOn = false;
      else return 0;
      storeOffsetEn();
      return 1;
    }
    else if (received2[1] == "GET"){
      printf("OFFSETEN: %d\t",homography);
      for (int i=0; i<4; i++) printf("OFFSETX%d: %.3f\tOFFSETY%d: %.3f\t",i,offset[0][i],i,offset[1][i]);
      Serial.println();
    }
    else {
      getOffset();
      storeOffset();
      storeOffsetEn();
      return 1;
    }
  }
  else if (received2[0] == "MIR"){
    bool val;
    if (received2[2] == "1") val = true;
    else if (received2[2] == "0") val = false;
    else return 0;
    if (received2[1] == "X") {
      mirrorX = val;
      storeMirrorX();
    }
    else if (received2[1] == "Y") {
      mirrorY = val;
      storeMirrorY();
    }
    else return 0;
    sendData();
    return 1;
  }
  else if (received2[0] == "ROT"){
    if (received2[1] == "1") rotation = true;
    else if (received2[1] == "0") rotation = false;
    else return 0;
    storeRotation();
    sendData();
    return 1;
  }
  else return 0;
}
//sprintf(msg, "{\"C\":%d%d%d%d%d,\"S\":%d,\"X0\":%d,\"Y0\":%d,\"I0\":%d,\"x\":%d,\"y\":%d}",homography,offset,mirrorX,mirrorY,rotation,255-sensitivity,Ix[0],Iy[0],Ii[0],Iold[0],Iold[1]);
//    Serial.println(msg);
 //   webSocket.broadcastTXT(msg);


//pinMode(battPin,INPUT);
   // pinMode(battState, INPUT);
 
void sendData() {
  if (rotation){
    for (int i=0; i<4; i++){
      uint16_t valTemp[2] = {Ix[i],Iy[i]};
      Ix[i] = valTemp[1];
      Iy[i] = valTemp[0];
    }
  }
  if (mirrorX) 
    for (int i=0; i<4; i++)
      Ix[i] = 1023 - Ix[i];
  if (mirrorY) 
    for (int i=0; i<4; i++)
      Iy[i] = 1023 - Iy[i];

  char msg[200];
  sprintf(msg,"{\"V\":%d,\"H\":%d,\"O\":%d,\"MX\":%d,\"MY\":%d,\"R\":%d,\"S\":%d",pointsVisible,homography,offsetOn,mirrorX,mirrorY,rotation,sensitivity);
  #ifdef FULL_SENSOR
    sprintf(msg+strlen(msg),",\"B\":%.2f,\"BS\":%d",tp.GetBatteryVoltage(),batteryState);
  #endif
  for(i=0; i<4; i++)
        if (pointsVisible > i) {
          sprintf(msg+strlen(msg),",\"X%d\":%d,\"Y%d\":%d,\"I%d\":%d",i,Ix[i],i,Iy[i],i,Ii[i]);
        }
  sprintf(msg+strlen(msg),"}");
  if (DEBUG) Serial.println(msg);
  webSocket.broadcastTXT(msg);
}

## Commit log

2020-09-27 Arduino v1.0.2, Module v1.0.1
2021-07-15 repository restructuring
    [Complete.f3z, Complete.step, ControllerBracket.step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]
2021-07-15 added calibration image
